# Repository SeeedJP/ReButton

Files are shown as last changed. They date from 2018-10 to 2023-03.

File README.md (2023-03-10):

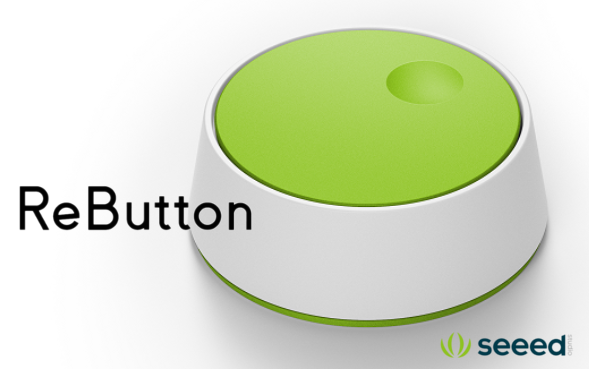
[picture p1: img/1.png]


ReButton is now available at [Seeed Bazaar](https://www.seeedstudio.com/ReButton-p-2930.html).

[日本語版ドキュメント](README-ja.md)

[HoL document in Simplified Chinese](IoTinAction_Hands-on%20Lab_ReButton%20OTA%20CN.pdf)

[!WARNING]
**Warning (Updated March 7, 2023)**

Due to the migration of the root certificate for Azure IoT Hub/Azure IoT Hub Device Provisioning Service planned from February 15, 2023 to February 15, 2024 [1], it is necessary to update ReButton's firmware to **v1.12 or later** [2].

Note that **OTA updates will fail** for firmware v1.0 to 1.11, so [firmware updates via SWD](#swd-serial-wire-debug) must be performed.

##### What is happening?
Between February 15, 2023 and February 15, 2024, the root certificate of the server certificate for Azure IoT Hub/Azure IoT Hub Device Provisioning Service will be gradually changed.

* Azure IoT Hub: February 15, 2023 to October 15, 2023
* Azure IoT Hub Device Provisioning Service: January 15, 2024 to February 15, 2024

##### What happens if I don't update the firmware?
After February 15, 2023, there is a possibility that ReButton will no longer be able to connect to Azure IoT Hub/IoT Central.

---
1. See "[Azure IoT TLS: Critical changes are almost here! (…and why you should care)](https://techcommunity.microsoft.com/t5/internet-of-things-blog/azure-iot-tls-critical-changes-are-almost-here-and-why-you/ba-p/2393169)" for more details.
2. Factory default firmware is "v1.0".
[!ENDWARNING]

# Overview

**Build IoT solutions with IoT Button!**

Seeed ReButton is a developer device for simple trigger actions, supporting multiple clicks and long press.
In addition, you can connect Seeed Grove sensors to add more data points.

1. When you push ReButton, it will power up and connect to Internet via pre-configured Wi-Fi.
2. ReButton will receive Device Twin changes from pre-configured Azure IoT Central or Azure IoT Hub.
3. ReButton will send Device to Cloud Message to pre-configured Azure IoT Central or Azure IoT Hub.
4. After D2C message is sent, ReButton will shutdown.

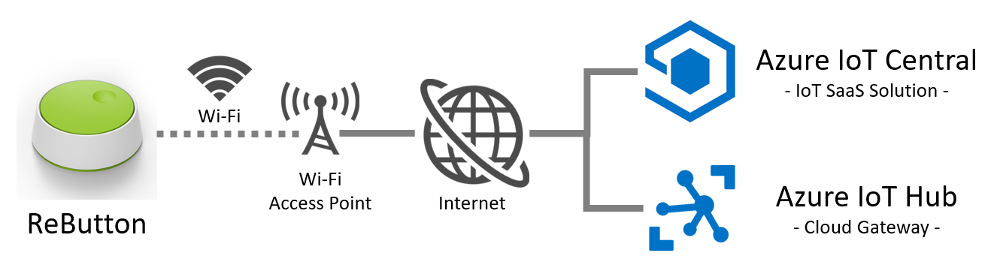
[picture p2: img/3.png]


# Key Features

## Multiple Trigger Support

* Single click
* Double click
* Triple click
* Long press (>3sec.)
* Super long press (>6sec.)

## Seeed Grove Sensor Support

Connect I2C or GPIO Grove sensors to the bottom of ReButton.
```
NOTE:
Software development/update is required.
```

## Cloud Support

Supports Azure IoT Central and Azure IoT Hub.

## OTA Support

You can update ReButton firmware over-the-air.

## Low Energy Design

ReButton runs with 2x AAA Alkaline battery.

# Quickstarts

## 1. Getting access to ReButton

Use AP Mode (Access Point Mode) to configure ReButton. **To avoid battery drain, ReButton will automatically shutdown in 10 minutes, at AP mode. So that we recommend you to setup IoT Hub or IoT Central, first.**

**AP Mode consume power. Please use fresh battery to start using ReButton.**

1. Hold button until RGB LED turns into White.
  RGB LED will start with Blue, Yellow, Cyan, then White. This will take about 10 seconds.

1. Release button and confirm ReButton is in AP mode.
  When ReButton successfully boots into AP Mode, RGB LED will blink in White.

1. Connect to AP
  Look for Wi-Fi Access Point `AZB-xxxxxxxxxxxx` and connect to it from your PC.
  (`xxxxxxxxxxxx` is MAC address of your ReButton Wi-Fi.)

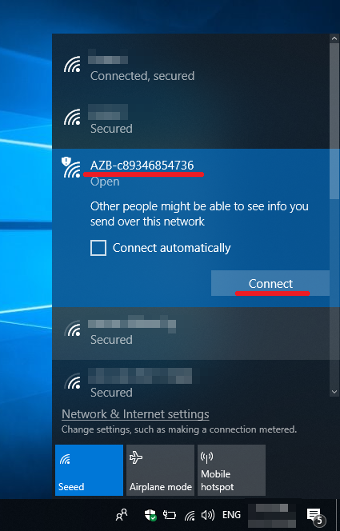
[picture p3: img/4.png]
  

4. Use a Web Browser to access ReButton - Home at `http://192.168.0.1`.

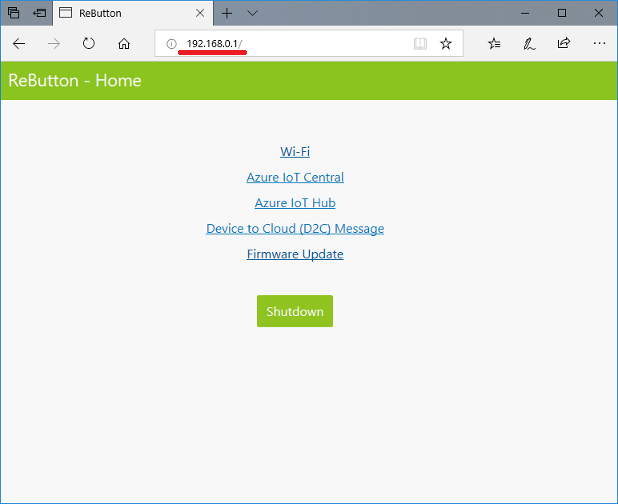
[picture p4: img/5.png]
  

## 2. Wi-Fi Configuration

Configure Wi-Fi settings to connect to Internet.

1. Click `Wi-Fi` at ReButton - Home.

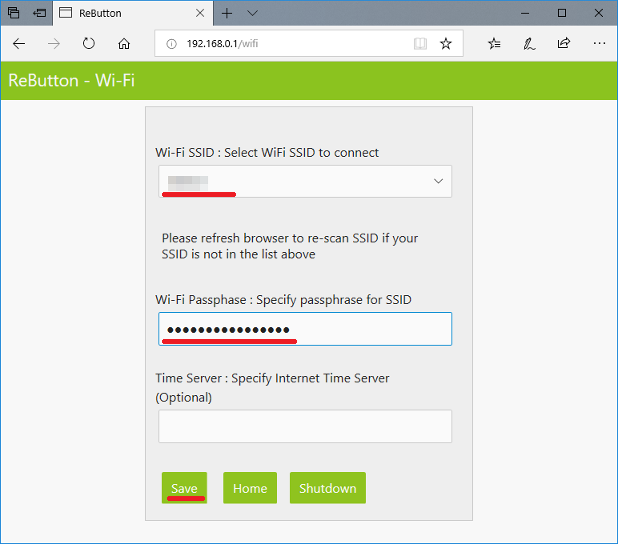
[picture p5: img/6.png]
  

2. Select your Wi-Fi Access Point from `Wi-Fi SSID` list.
  If you do not see your Access Point, refresh browser.
1. Enter `Wi-Fi Passphrase` for your Wi-Fi AP.
1. In case you would like to use specific Internet Time Server, enter FQDN to `Time Server`.
  _Default Internet Time Server is pool.ntp.org -> cn.pool.ntp.org -> europe.pool.ntp.org -> asia.pool.ntp.org -> oceania.pool.ntp.org ._

1. Click `Save`.

## 3. Cloud Configuration

### 3-1. Azure IoT Hub

**NOTE: Skip to next section if you would like to connct to Azure IoT Central.**

In order to send Device to Cloud (D2C) message to Azure IoT Hub, save Connection String in ReButton.

**To get the connection string, [This](IoT_Hub.md) page could be helpful.**

1. Browse to ReButton - Home page then click `Azure IoT Hub`.
1. Paste Connection String to `Azure IoT Hub connection string`.
1. Click `Save`.

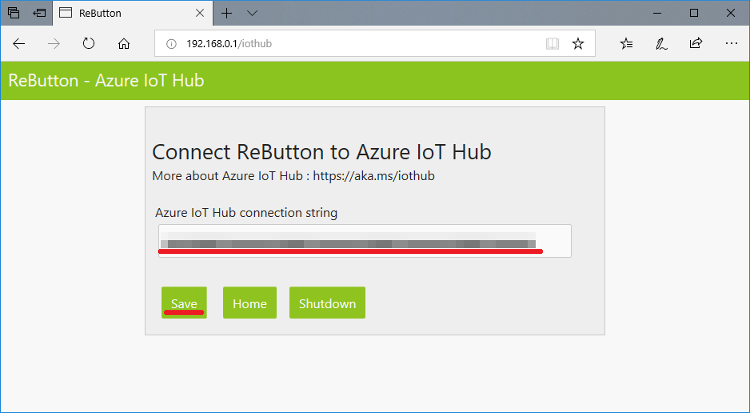
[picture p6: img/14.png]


### 3-2. Azure IoT Central

**NOTE: Skip this section if you already configured IoT Hub at section 3-1.**

In order to send Device to Cloud (D2C) message to Azure IoT Central, save device provisioning information in ReButton.

In order to connect ReButton to Azure IoT Central, the device template for ReButton needs to be defined in you Azure IoT Central Application. _Please refer [Azure IoT Central Document](https://docs.microsoft.com/en-us/azure/iot-central/howto-set-up-template) for more information._

1. Create a device template for ReButton in Azure IoT Central.

|Display name|Name|Capability type|Semantic type|Schema|Unit|
|:--|:--|:--|:--|:--|:--|
|Battery Voltage|batteryVoltage|Telemetry|Voltage|Double|Volt|
|Message|message|Telemetry|Event|String||
|Action Number|actionNum|Telemetry|Event|String||

- Battery Voltage

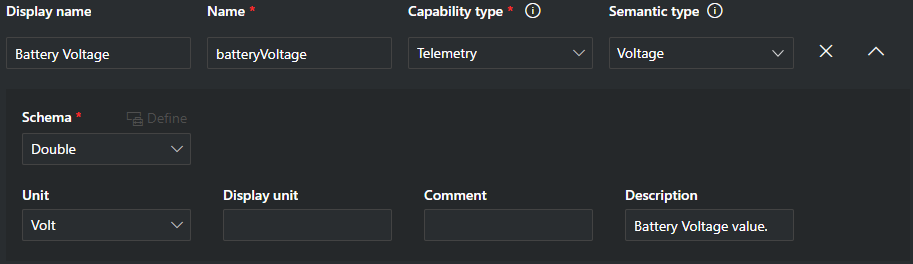
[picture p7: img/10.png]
  

- Message

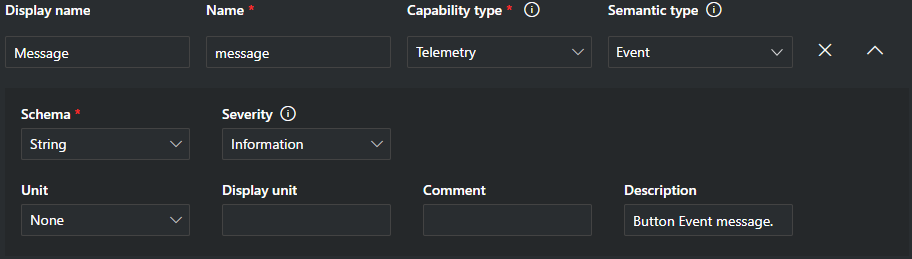
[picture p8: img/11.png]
  

- Action Number

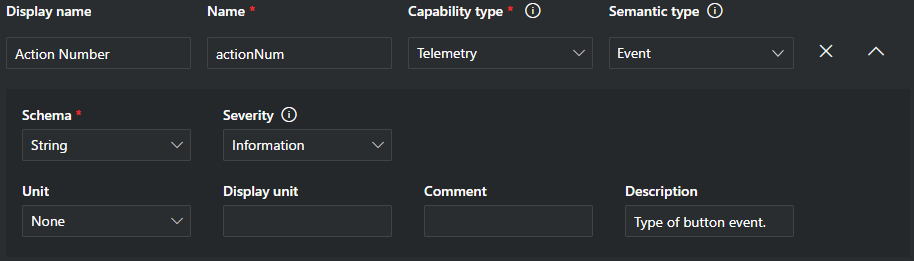
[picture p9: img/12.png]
  

2. Create a device in Azure IoT Central.

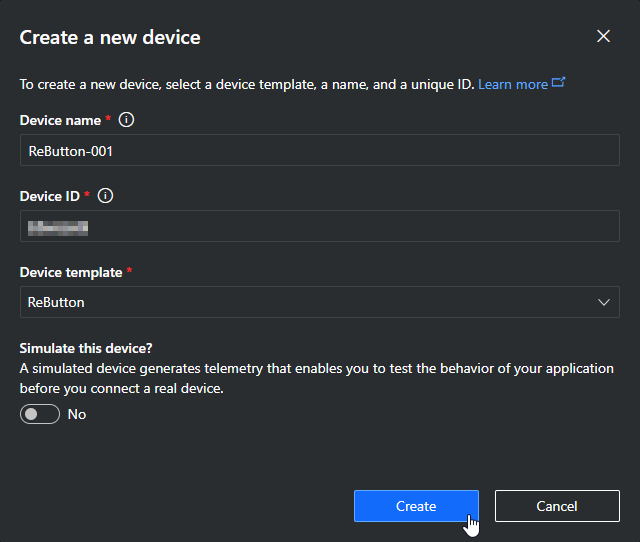
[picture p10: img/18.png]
  

3. Click `Connect` on Top Right corner of Azure IoT Central page.

  

4. Copy 3 values.
    1. `Scope ID`
    1. `Device ID`
    1. `Primary Key`

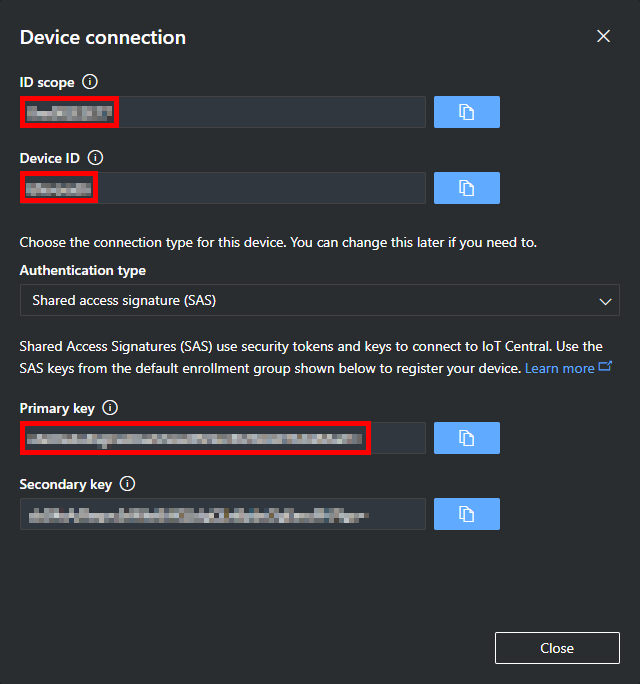
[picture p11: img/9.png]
  

5. Browse to ReButton - Home page then click `Azure IoT Central`.
1. Enter `Scope ID`, `Device ID`, `SAS Key` from Azure IoT Central.
1. Click `Save`.

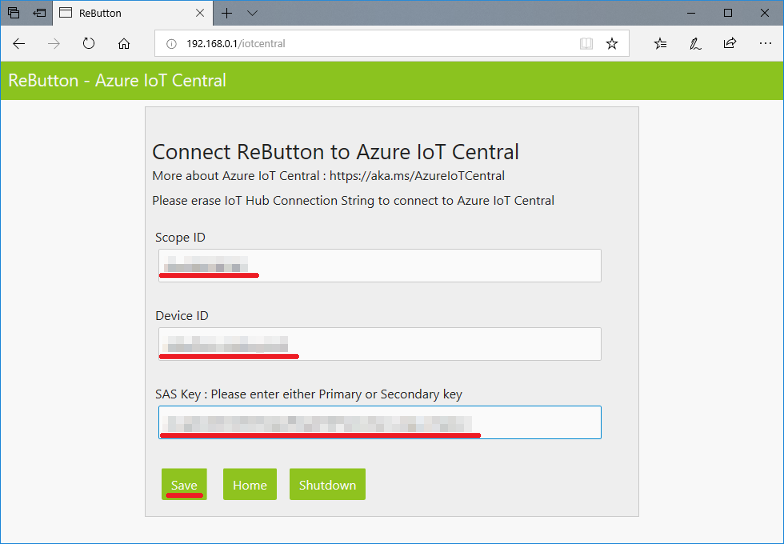
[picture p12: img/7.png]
  

## 4. Power off

Exit AP Mode and power off ReButton.

1. Click `Shutdown` button.

# Other informations
## Device To Cloud (D2C) Messsage

Button push will trigger D2C message to the cloud.
ReButton supports 5 types of button triggers and default D2C message strings are following.

|Clicks|RGB led|actionNum|message|
|:--|:--|:--|:--|
|Single click|Blue|1|"Single click"|
|Double click|Lime|2|"Double click"|
|Triple click|Magenta|3|"Triple click"|
|Long press (> 3sec.)|Yellow|10|"Long press"|
|Super long press (> 6sec.)|Cyan|11|"Super long press"|

Examples of D2C message:
```json
{
  "actionNum": "1",
  "message": "Single click",
  "batteryVoltage": 2.59
}

{
  "actionNum": "2",
  "message": "Double click",
  "batteryVoltage": 2.59
}

{
  "actionNum": "3",
  "message": "Triple click",
  "batteryVoltage": 2.59
}

{
  "actionNum": "10",
  "message": "Long press",
  "batteryVoltage": 2.59
}

{
  "actionNum": "11",
  "message": "Super long press",
  "batteryVoltage": 2.59
}
```

# Firmware Development
## Development environment
Please download and install [Arduino IDE](https://www.arduino.cc/en/Main/Software), not web editor.

On the preferenceof Arduino IDE, enter `https://www.seeed.co.jp/package_SeeedJP_index.json` to "Additional Boards Manager URLs".

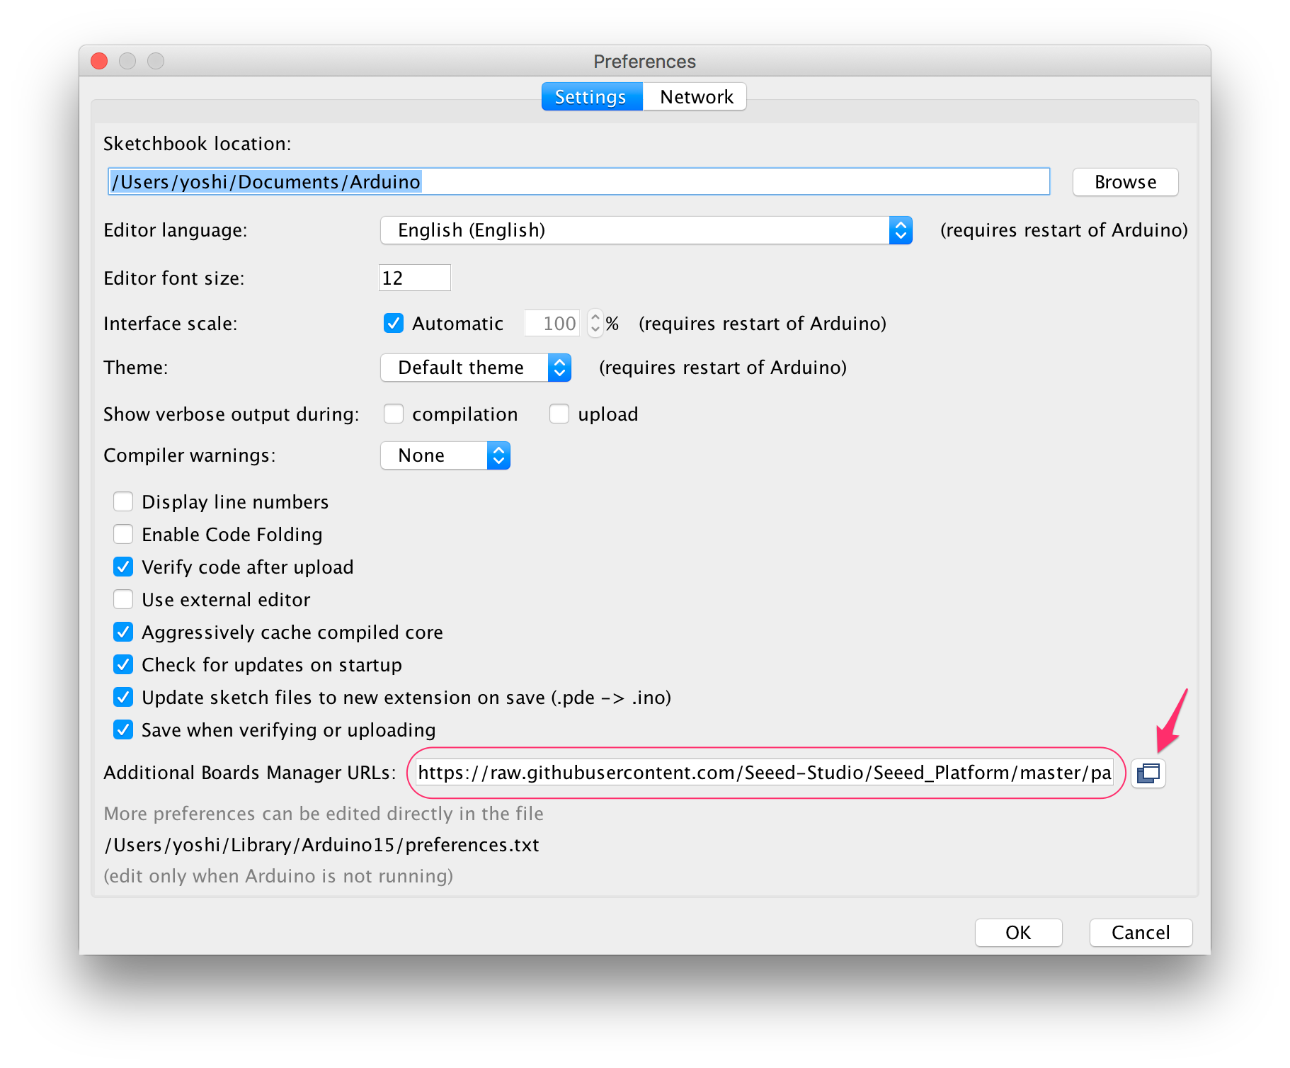
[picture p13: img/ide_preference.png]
ide_preference


Then goes to the Boards Manager from Tools > Board. And search ReButton board package by entering "rebutton". Then choose the candidate and click the "install" button.

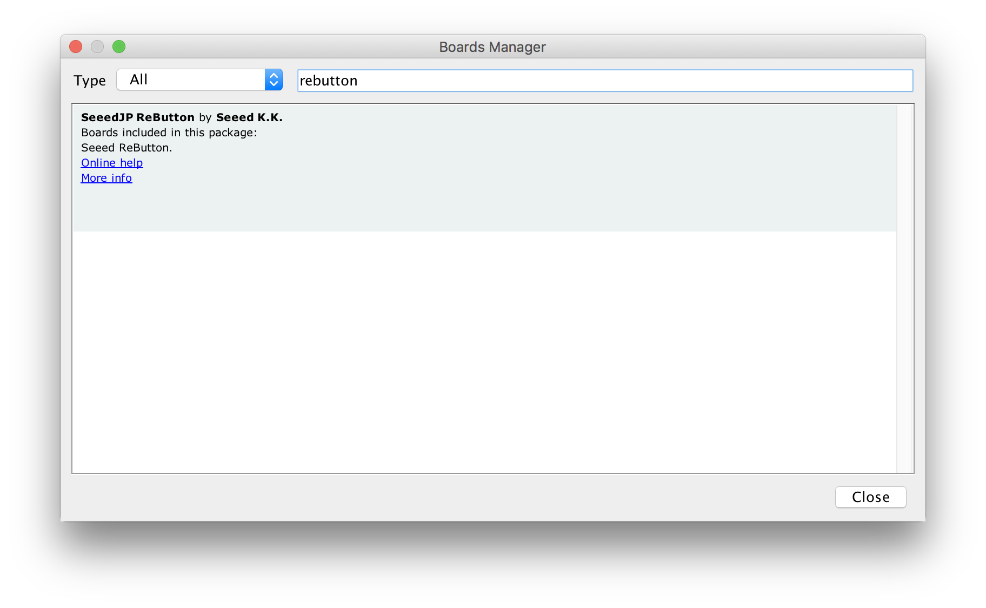
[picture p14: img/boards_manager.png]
boards_manager


After the install process ( it may take a few minutes ) you can choose "ReButton" through Tool -> Board on Arduino IDE.

## Firmware sample code
The source code is:
* [ReButton App](https://github.com/SeeedJP/ReButtonApp)

## Firmware OTA Update
ReButton supports Firmware OTA.
Browse to `Firmware Update` page to see the current vesrion of firmware and update to new firmware.

#### Current Firmware Version
Browse to ReButton - Home then click `Firmware Update` to see current firmware version of ReButton.

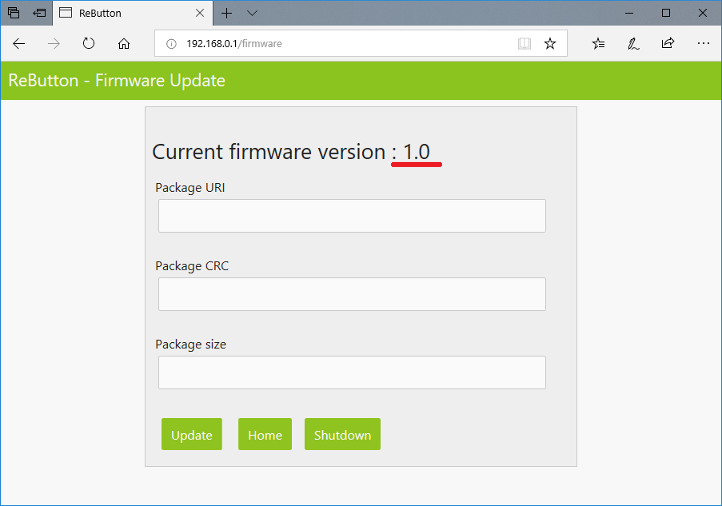
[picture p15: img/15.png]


#### How to update firmware through OTA
For OTA firmware update process, please refer [this](OTA.md) page.

## SWD (Serial Wire Debug)

ReButton has SWD pads for MCU development. **Please do this on your own risk,**  it is easy to make your ReButton brick.
Following picture show the SWD signals of the PAD. You can connect this PADs to debug adapters by using [TC2030-CTX 6-Pin Cable](http://www.tag-connect.com/TC2030-CTX) or solder directly to the PADs.

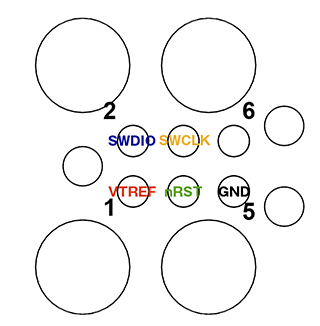
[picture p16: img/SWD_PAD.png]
SWD PADs


We are preparing for providing software development informations and affordable debug adapter. For your recovering purpose, you can download ReButton default firmware binary 'ReButton.1.0_with_bootloader.bin' from [here](https://github.com/SeeedJP/ReButton/tree/master/firmware). You need to flash this binary for target `STM32F412RG` and flash address `0x0800 0000` since this default firmware binary includes bootloader.

1. Connect the debug adapter to ReButton's SWD pads.
2. Install batteries.
3. **While holding (physical) button of ReButton**, execute download.

example:
```
openocd -f /usr/local/share/openocd/scripts/interface/cmsis-dap.cfg -c 'transport select swd' -f /usr/local/share/openocd/scripts/target/stm32f4x.cfg -c "program ReButton.1.0_with_bootloader.bin verify reset exit 0x08000000"
```

When you flash a binary without bootloader (such as `ReButtonApp.1.x.bin`), you should flash address `0x0800 C000`.

# Specification

## Hardware

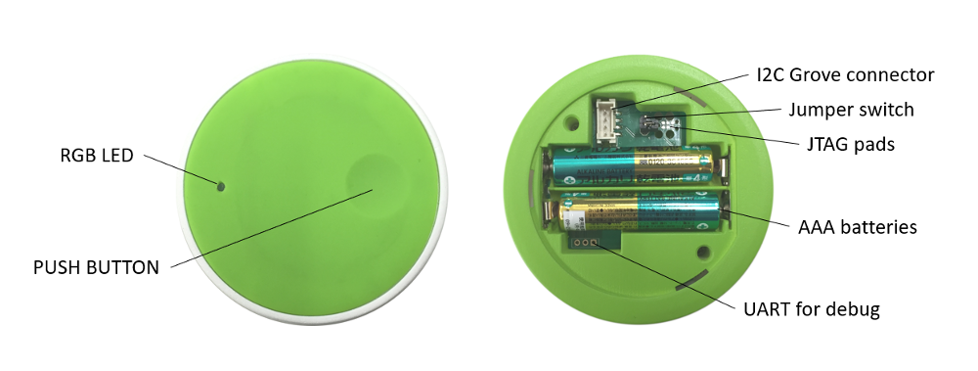
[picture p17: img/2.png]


|Description|Value|
|:--|:--|
|MCU module|MXCHIP EMW3166|
|Input|1x Push button|
|Output|1x RGB led|
|Extension|1x I2C Grove connector (3.3V I/O)|
|Extras|1x Jumper switch|
||1x SWD pads|
||1x UART for debugging|
|Power supply|2x AAA Alkaline batteries (LR03)|
|Internal supply voltage|3.3V|
|Dimension|70mm\*70mm\*25mm|

## Design files
* [Schematics](https://github.com/SeeedJP/ReButton/tree/master/electronics)
* [Housing](https://github.com/SeeedJP/ReButton/tree/master/mechanicals)


These files are licensed under [CC-BY-SA](https://creativecommons.org/licenses/by-sa/4.0/deed.en).

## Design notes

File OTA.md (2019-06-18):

## Step 1 : Uploading firmware binary to Azure Storage

You can upload ReButton firmware binary to Azure Storage wiith [Azure CLI](https://docs.microsoft.com/en-us/cli/azure/) tool.

### 1.1 : Install Azure CLI

Please refer to Azure CLI install instruction [here](https://docs.microsoft.com/en-us/cli/azure/install-azure-cli).

And [Using the Azure CLI with Azure Storage](https://docs.microsoft.com/en-us/azure/storage/common/storage-azure-cli) page is helpful to process things on this instruction.

### 1.2 : Create a new storage account

To use Azure Storage, you need a storage account. You can create a new Azure Storage account after you've configured your computer to connect to your subscription.

```bash
az storage account create \
    --location <location> \
    --name <account_name> \
    --resource-group <resource_group> \
    --sku <account_sku>
```
e.g.
```bash
az storage account create --location japaneast \
--name seeedkk --resource-group ReButton --sku Standard_GRS
```
You can use same resource group to IoT Hub.

### 1.3: Set default Azure storage account

First, display your storage account keys by using following account.
```bash
az storage account keys list \
    --account-name <account_name> \
    --resource-group <resource_group> \
    --output table
```
e.g.
```bash
az storage account keys list --account-name seeedkk \
--resource-group ReButton
```

Now that you have the key, you can define it and the account name as environment variables:

```bash
export AZURE_STORAGE_ACCOUNT=<account_name>
export AZURE_STORAGE_KEY=<key>
```

### 1.4 Create a container

Every blob in Azure storage must be in a container. You can create a container by using following command.
```bash
az storage container create --name <container_name> \
--public-access container
```

### 1.5 Upload a blob to a container

And you can upload firmware binary to Azure storage with following command.
```bash
az storage blob upload \
    --file <local_file_path> \
    --container-name <container_name> \
    --name <blob_name>
```
e.g.
```bash
az storage blob upload -f ReButtonApp.1.0.bin \
--container-name rebuttonfirm --name ReButtonApp.1.0.bin
```

### 1.6: Grab the URL

You can find the URL of uploaded blob on [Azure Portal](https://portal.azure.com).

On the portal, please find `Storage accounts` in `All services` and then choose storage accounts you used to upload, and choose `Blobs`.

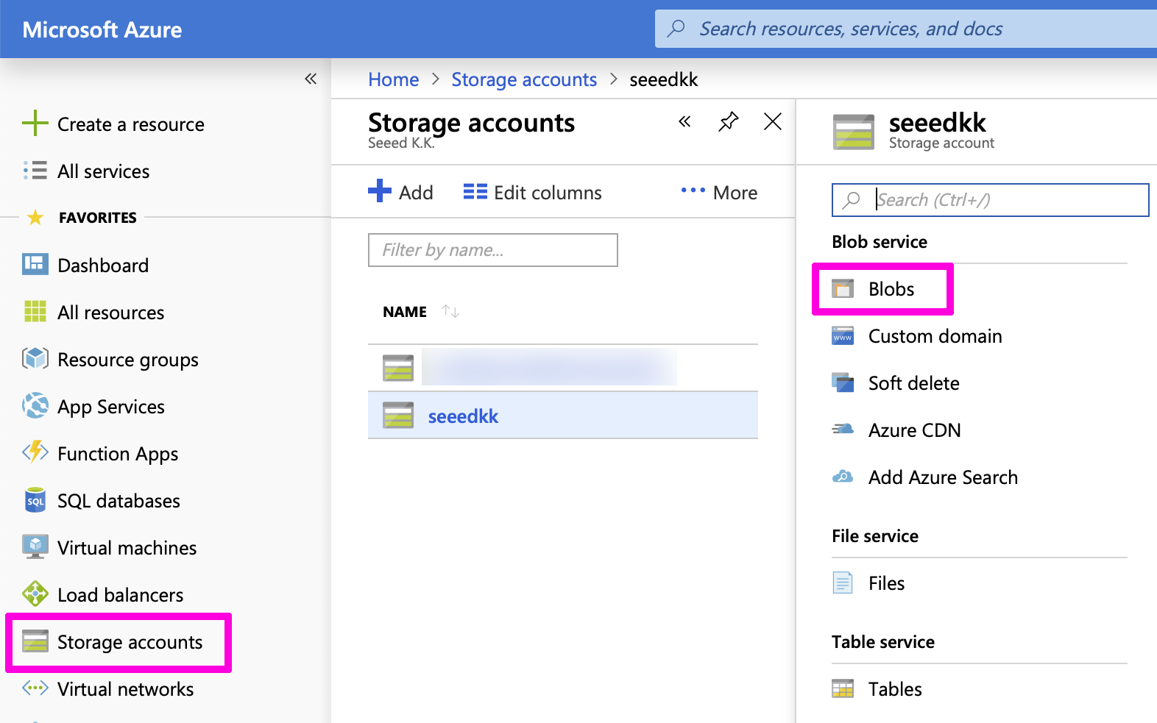
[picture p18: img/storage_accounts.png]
storage accounts


In the container you have just used, you can find uploaded file(blob). By clicking the filename, you can refer the URL.

## Step 2: Calculate CRC

CRC can calclulate with [generatecrc](https://github.com/SeeedJP/ReButton/tree/master/tools/generatecrc) command we are providing in this repository.

example:
```bash
$ cd generatecrc
$ ./generatecrc ../ReButtonApp.1.0.bin
========== ReButton Firmware Information ==========

Package path: ../ReButtonApp.1.0.bin
Package CRC: 0xbc3b
Package size: 641924

===================================================
```

## Step 3: OTA process

**OTA consume power. Please use fresh battery, not to interrupt OTA process.**

1. Enter ReButton to AP mode by press hold the button until RGB LED turns into White. 
   (reminder: connect to the AP `AZB-xxxxxxxxxxxx` and the URL of the page is `http://192.168.0.1`)
1. Browse to ReButton - Home page then click `Firmware Update`.
1. Enter following information.
  - `Package URI` - got on Step 1.6
  - `Package CRC` - got on Step 2.
  - `Package Size` - got on Step 2.
1. **While holding (physical) button of ReButton**, click `Update`.
1. Hold button until RGB LED starts blinking. ReButton is downloading the firmware image, checking CRC, and flashing new image. **This will take about 30 seconds.**
1. Release button when RGB LED turns into White. So that you are entering AP mode with new firmware.
1. Please set-up ReButton Wi-Fi connection and Azure connection settings on this AP mode.

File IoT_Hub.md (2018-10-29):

# Getting started with Azure IoT Hub
---
Legal Disclaimer  
This page was provided just to provide a convenience for users. Seeed is not responsible for any errors or omissions, or for the results obtained from the use of this information. All information in this page is provided "as is", with no guarantee of completeness, accuracy, timeliness or of the results obtained from the use of this information.

---

For more information about "Azure IoT Hub", please refer to [Azure IoT Hub](https://docs.microsoft.com/en-us/azure/iot-hub/about-iot-hub).

For pricing information about IoT Hub tiers refer to [IoT Hub pricing](https://azure.microsoft.com/en-us/pricing/details/iot-hub/).

## Step 1 : Login to Azure Portal

If you don't have an active Azure subscription, create a [free account](https://azure.microsoft.com/free) before you begin.

## Step 2 : Create Azure IoT Hub

### 2.1 : Navigate to [Azure Portal](http://portal.azure.com) with browser

### 2.2 : Click `Create a resource` on top left corner  

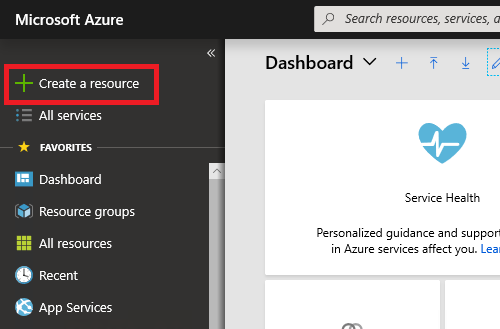
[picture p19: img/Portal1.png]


### 2.3 : Select `Internet of Things`, then `IoT Hub`
  
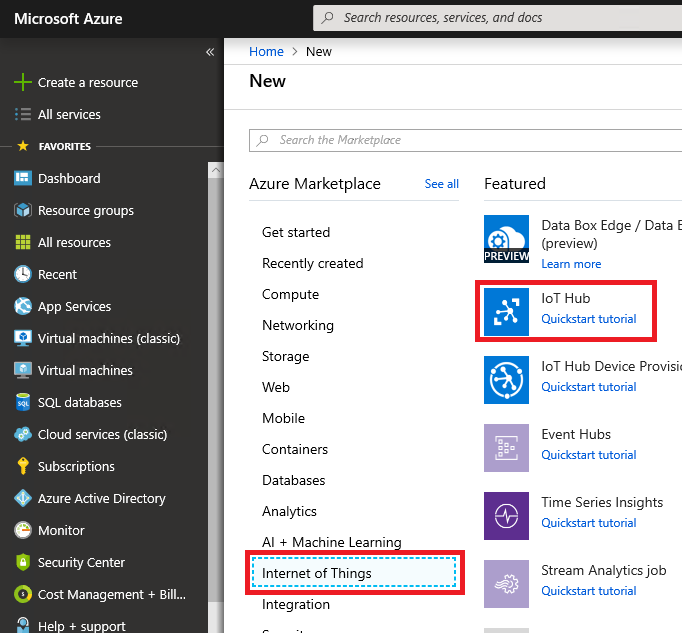
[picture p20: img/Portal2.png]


### 2.4 : Fill out following fields

|Field | Description  |
|---|---|
|Subscription | Your subscription.  Select from the list. |
|Resource Group  | A resource group to manage all the resources.  Select existing one from the list or create new group. |
|Region | Location of Azure Data Center.  Select the one close to you. |
|IoT Hub Name | Provide a globally unique name for your IoT Hub. |

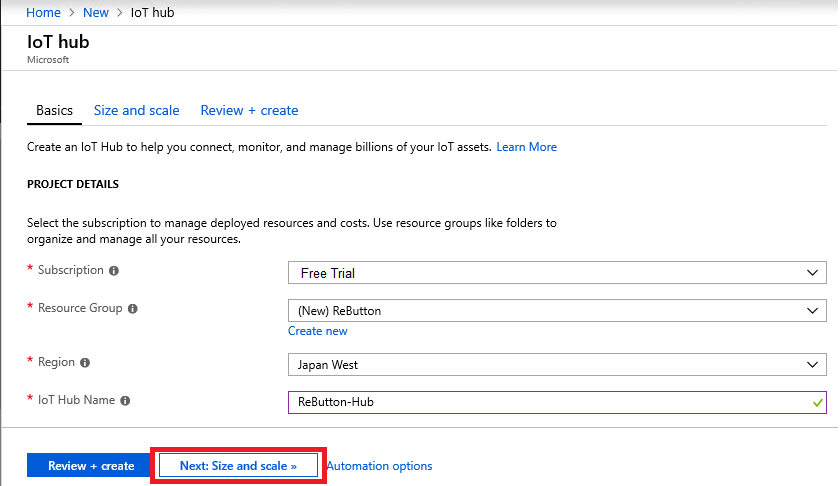
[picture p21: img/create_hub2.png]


### 2.5 : Size and Scale

Click `Size and scale`, then select `F1 : Free tier`.  

_NOTE: Only one F1 Free tier is available per subscription. If you already have F1 IoT Hub, you may need non-free tier IoT Hub. More about [IoT Hub tier](https://docs.microsoft.com/en-us/azure/iot-hub/iot-hub-scaling)._

### 2.6 : Click `Review + create` button

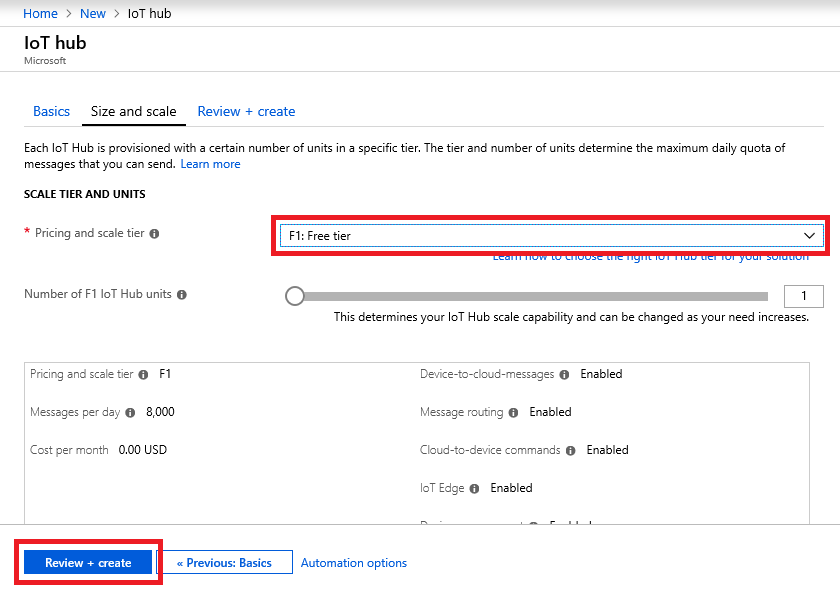
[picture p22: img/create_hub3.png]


### 2.7 : Create Azure IoT Hub

Review your settings then, click `Create` button.

Wait until the deployment completes.

## Step 3 : Create IoT Device

### 3.1 : Navigate to Azure IoT Hub instance

After your new Azure IoT Hub is deployed, click your Azure IoT Hub resource to navigate to Azure IoT Hub instance you just created.

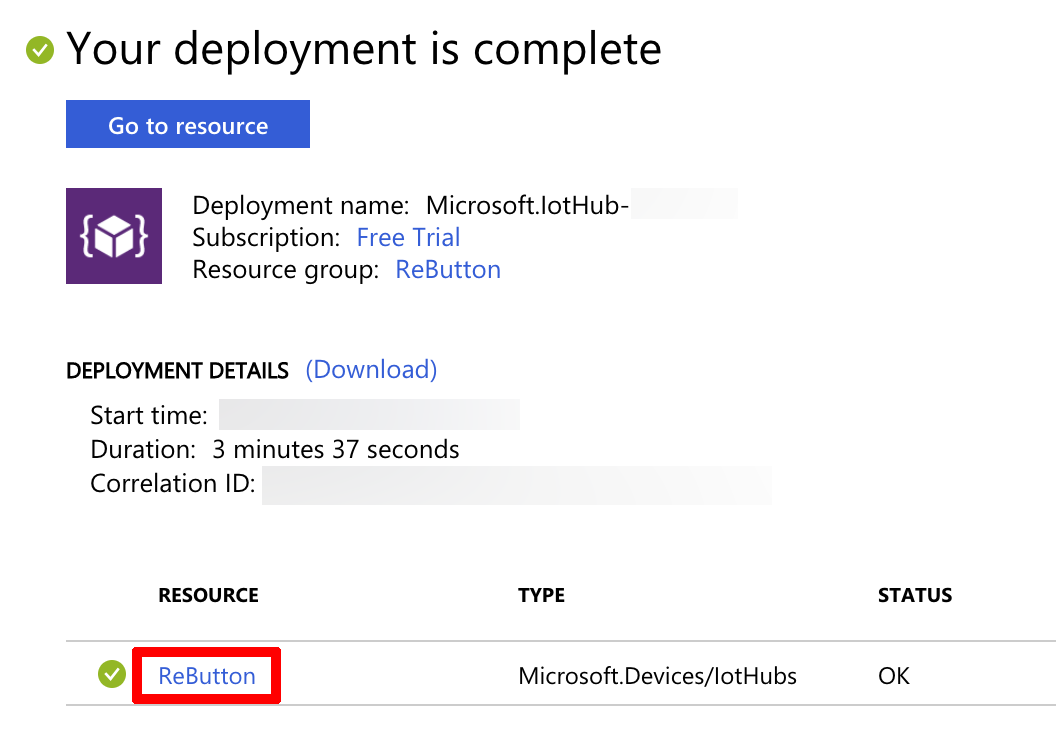
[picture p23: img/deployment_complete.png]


### 3.2 : Create IoT Device

Click  `IoT Devices`

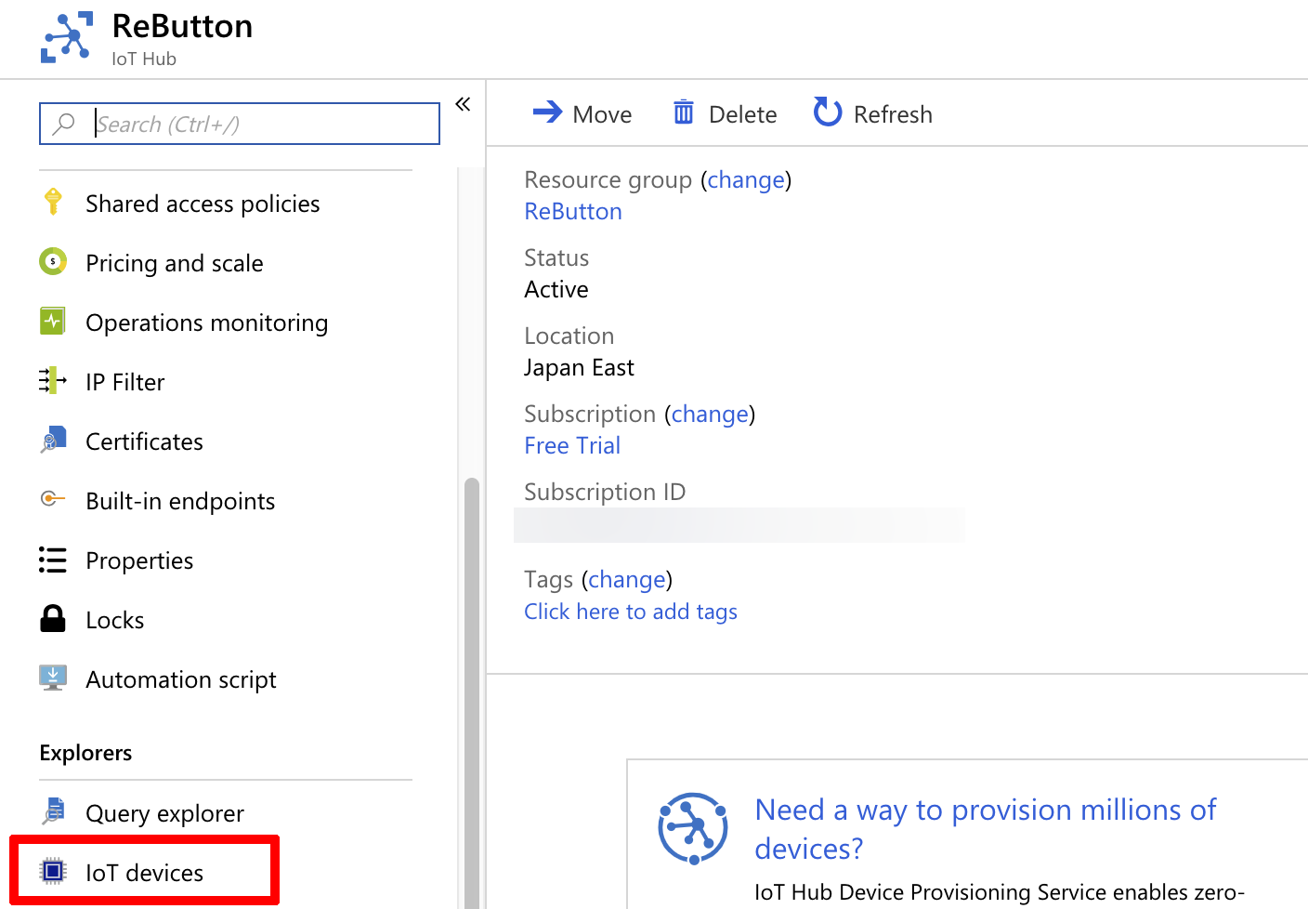
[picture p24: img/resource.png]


### 3.3 : Click `Add` button

To add a new IoT Device to your Azure IoT Hub

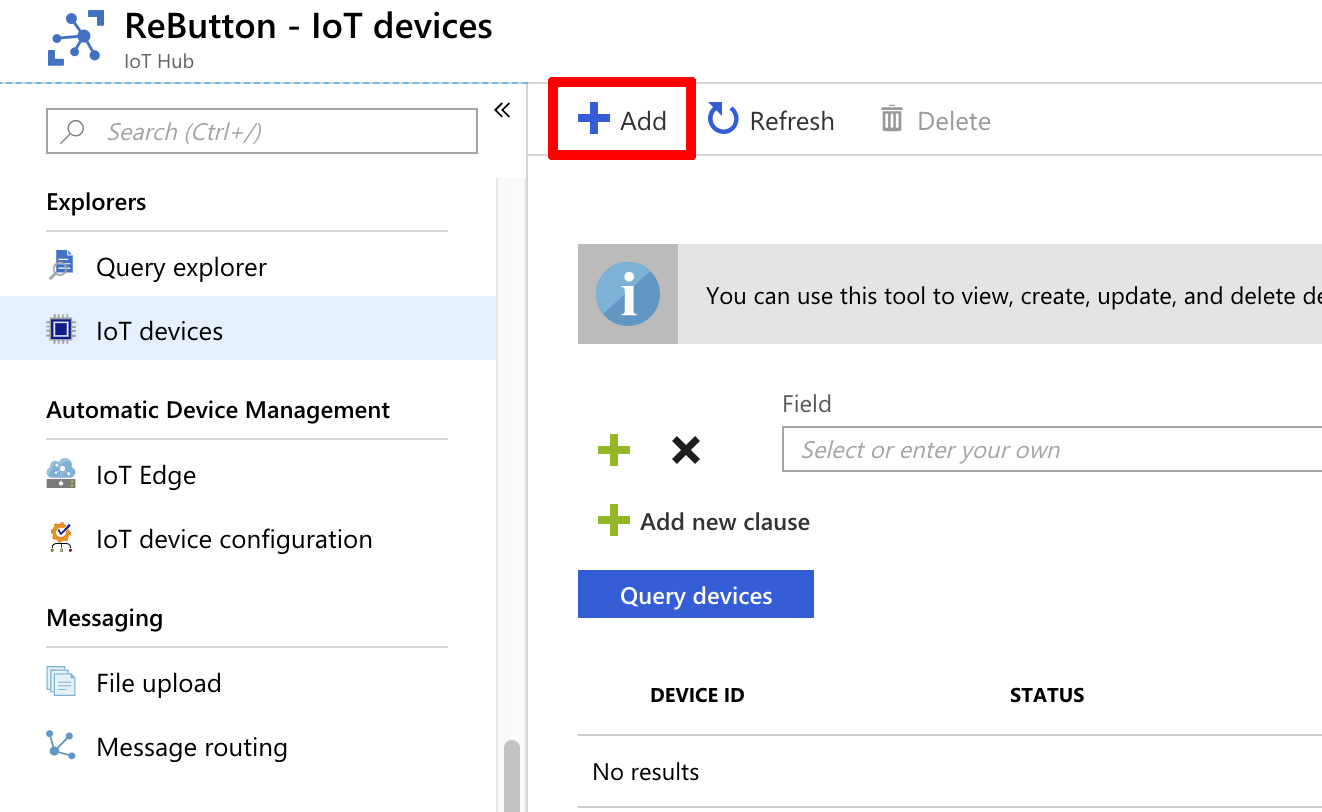
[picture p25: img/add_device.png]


### 3.4 : Provide a name to new IoT Device

Set Device Id (Name) for your ReButton, then click `Save` button

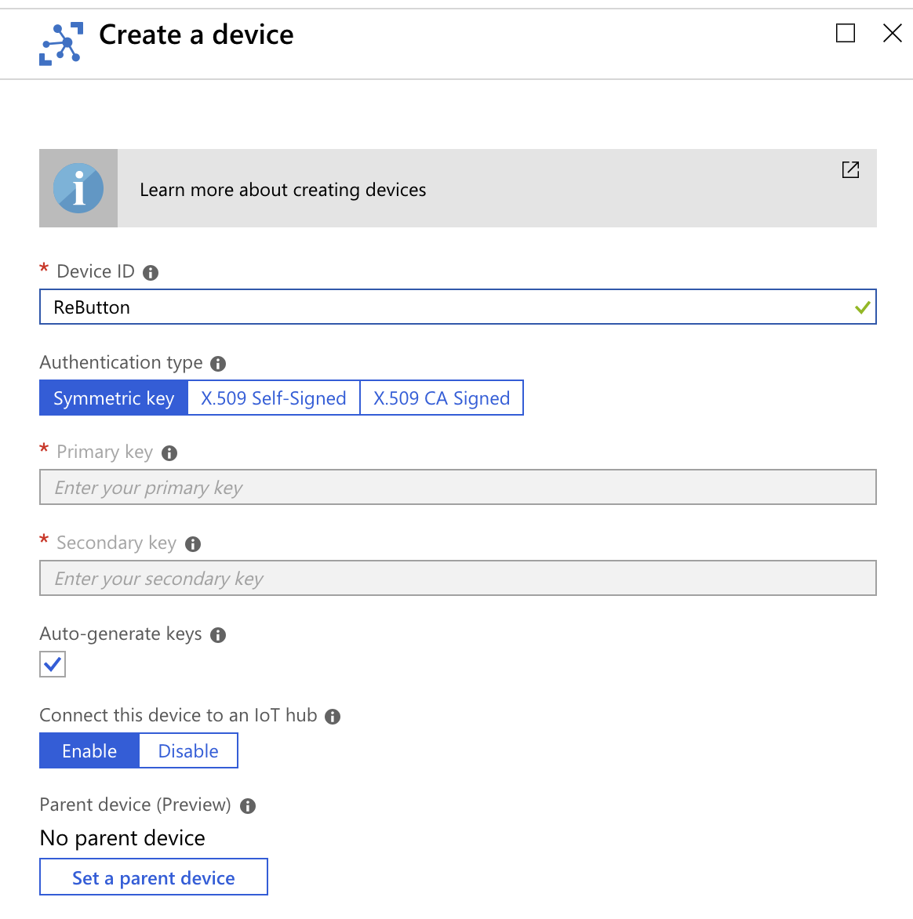
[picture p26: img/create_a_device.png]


### 3.5 : Verify a new IoT Device for ReButton is created

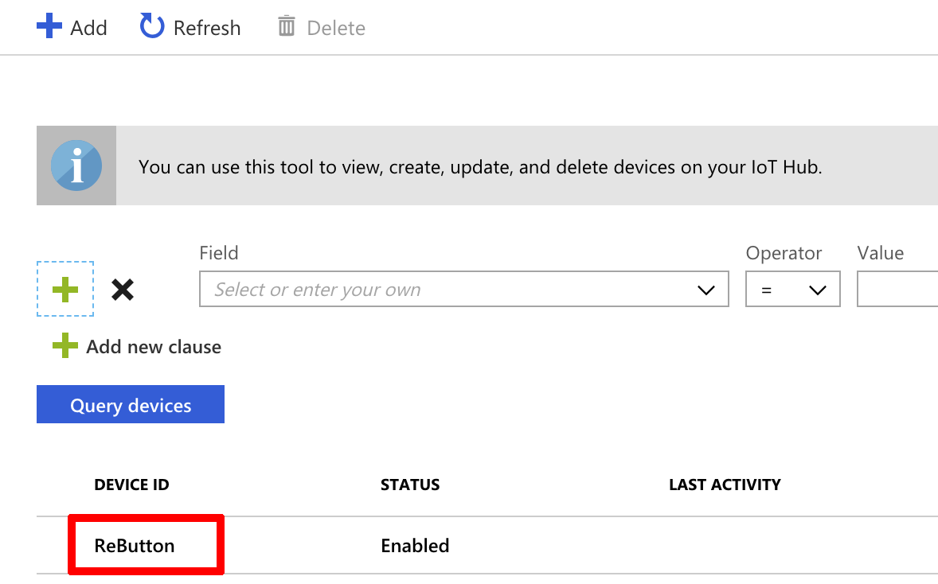
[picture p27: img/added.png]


## Step 4 : Connect ReButton to Azure IoT Hub

In order for ReButton to securely connect to Azure IoT Hub, Connection String needs to be saved  to ReButton.

### 4.1 : Open Device Detail page

Click on the newly created IoT Device (e.g. ReButton) to open `Device details` page.

### 4.2 : Copy `Connection String`

Copy either Primary or Secondary Connection String by clicking button on the right

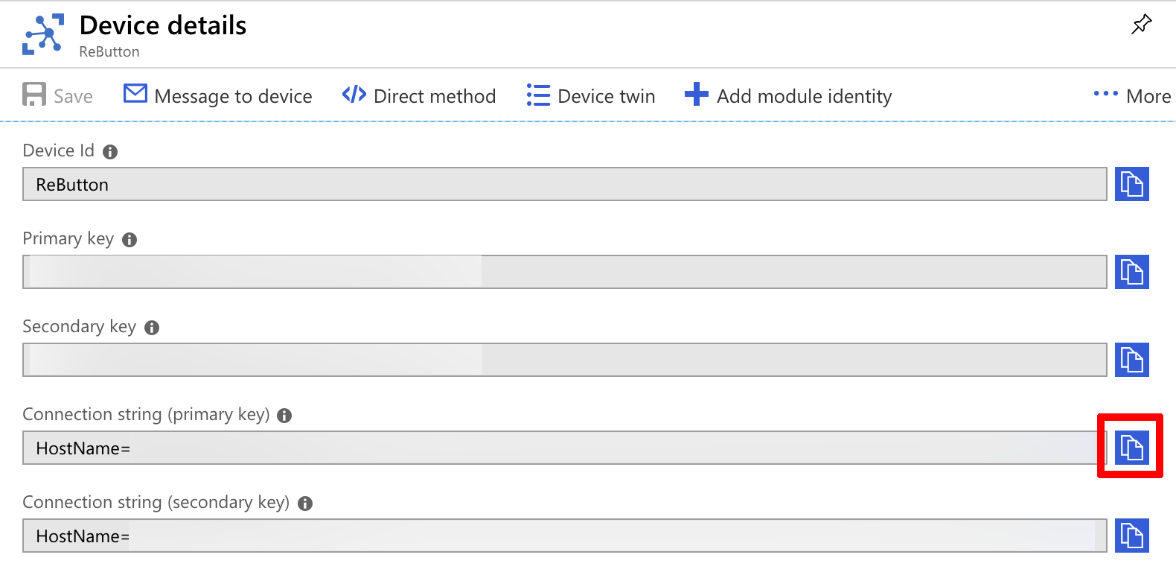
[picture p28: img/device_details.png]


### 4.3 : Save Connection String to ReButton Device

Please refer to [3-1. Azure IoT Hub](README.md#3-1-azure-iot-hub)

## Step 5 : Verify Connection

With [Azure CLI](https://docs.microsoft.com/en-us/cli/azure/) tool, verify ReButton sends messages to Azure IoT Hub.

### 5.1 : Install Azure CLI

Please refer to Azure CLI install instruction [here](https://docs.microsoft.com/en-us/cli/azure/install-azure-cli)

### 5.2 : Install IoT Extension

Install [Azure IoT extension for Azure CLI](https://github.com/Azure/azure-iot-cli-extension) with following command

```
$ az extension add --name azure-cli-iot-ext
```  

### 5.3 : Login to Azure

After getting Azure CLI installed, login to Azure

```
$ az login
```  

Web browser will launch to complete login process

### 5.4 : List Azure IoT Hub

Let's list your IoT Hub(s)  

```
$ az iot hub list
``` 

### 5.5 : Monitor Device to Cloud (D2C) message

To monitor messages from `ReButton` to IoT Hub, please run command.  

_NOTE: Replace [IoTHub Name] with your Azure IoT Hub instance from list command above._

```
$ az iot hub monitor-events -n [IoTHub Name] --properties anno sys --timeout 0
```

For more information about Azure CLI command, please see help,  

```
$ az iot hub monitor-events --help
```

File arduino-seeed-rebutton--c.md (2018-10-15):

---
platform: arduino
device: Seeed ReButton
language: c
---

Run a simple C sample on Seeed ReButton device running Arduino
===
---

# Table of Contents

-   [Introduction](#Introduction)
-   [Step 1: Prerequisites](#Prerequisites)
-   [Step 2: Prepare your Device](#PrepareDevice)
-   [Step 3: Configure and Run the Sample](#Run)
-   [Next Steps](#NextSteps)

# Introduction

This document describes how to connect Seeed ReButton device running C with Azure IoT Hub. This multi-step process includes:
-   Configuring Azure IoT Hub
-   Registering your IoT device
-   Configure the device and run the sample

# Step 1: Prerequisites

You should have the following items ready before beginning the process:

-   [Setup your IoT hub][lnk-setup-iot-hub]
-   [Provision your device and get its credentials][lnk-manage-iot-hub]
-   Seeed ReButton device.

# Step 2: Prepare your Device

# Step 3: Run the sample

## 3.1 Access to ReButton

Use AP Mode (Access Point Mode) to configure ReButton.

1. Hold button until RGB LED turns into White.  
  RGB LED will start with Blue, Yellow, Cyan, then White.  
  This will take about 10 seconds.

1. Release button and confirm ReButton is in AP mode.  
  When ReButton successfully boots into AP Mode, RGB LED will blink in White.

1. Connect to AP  
  Look for Wi-Fi Access Point `AZB-xxxxxxxxxxxx` and connect to it from your PC.  
  `xxxxxxxxxxxx` is MAC address of your ReButton Wi-Fi.  
  

1. Use a Web Browser to access ReButton - Home at `http://192.168.0.1`.  
  

## 3.2 Wi-Fi Configuration

Configure Wi-Fi settings to connect to Internet.

1. Click `Wi-Fi` at ReButton - Home.
1. Select your Wi-Fi Access Point from `Wi-Fi SSID` list.  
  If you do not see your Access Point, refresh browser.
1. Enter `Wi-Fi Passphrase` for your Wi-Fi AP.
1. In case you would like to use specific Internet Time Server, enter FQDN to `Time Server`.  
  Default Internet Time Server is pool.ntp.org -> cn.pool.ntp.org -> europe.pool.ntp.org -> asia.pool.ntp.org -> oceania.pool.ntp.org .

1. Click `Save`.



### 3.3 Azure IoT Hub

In order to send Device to Cloud (D2C) message to Azure IoT Hub, save Connection String in ReButton.

1. Browse to ReButton - Home page then click `Azure IoT Hub`.
1. Paste Connection String to `Azure IoT Hub connection string`.
1. Click `Save`.



## 3.4 Power off

Exit AP Mode and power off ReButton.

1. Click `Shutdown` button.

## 3.5 Device To Cloud (D2C) Messsage

Button push will trigger D2C message to the cloud.  
ReButton supports 5 types of button triggers and default D2C message strings are following.

|Clicks|RGB led|actionNum|message|
|:--|:--|:--|:--|
|Single click|Blue|1|"Single click"|
|Double click|Lime|2|"Double click"|
|Triple click|Magenta|3|"Triple click"|
|Long press (> 3sec.)|Yellow|10|"Long press"|
|Super long press (> 6sec.)|Cyan|11|"Super long press"|

Examples of D2C message:
```json
{
  "actionNum": "1",
  "message": "Single click",
  "batteryVoltage": 2.59
}

{
  "actionNum": "2",
  "message": "Double click",
  "batteryVoltage": 2.59
}

{
  "actionNum": "3",
  "message": "Triple click",
  "batteryVoltage": 2.59
}

{
  "actionNum": "10",
  "message": "Long press",
  "batteryVoltage": 2.59
}

{
  "actionNum": "11",
  "message": "Super long press",
  "batteryVoltage": 2.59
}
```

# Next Steps

You have now learned how to run a sample application that collects sensor data and sends it to your IoT hub. To explore how to store, analyze and visualize the data from this application in Azure using a variety of different services, please click on the following lessons:

-   [Manage cloud device messaging with iothub-explorer]
-   [Save IoT Hub messages to Azure data storage]
-   [Use Power BI to visualize real-time sensor data from Azure IoT Hub]
-   [Use Azure Web Apps to visualize real-time sensor data from Azure IoT Hub]
-   [Weather forecast using the sensor data from your IoT hub in Azure Machine Learning]
-   [Remote monitoring and notifications with Logic Apps]   

[Manage cloud device messaging with iothub-explorer]: https://docs.microsoft.com/en-us/azure/iot-hub/iot-hub-explorer-cloud-device-messaging
[Save IoT Hub messages to Azure data storage]: https://docs.microsoft.com/en-us/azure/iot-hub/iot-hub-store-data-in-azure-table-storage
[Use Power BI to visualize real-time sensor data from Azure IoT Hub]: https://docs.microsoft.com/en-us/azure/iot-hub/iot-hub-live-data-visualization-in-power-bi
[Use Azure Web Apps to visualize real-time sensor data from Azure IoT Hub]: https://docs.microsoft.com/en-us/azure/iot-hub/iot-hub-live-data-visualization-in-web-apps
[Weather forecast using the sensor data from your IoT hub in Azure Machine Learning]: https://docs.microsoft.com/en-us/azure/iot-hub/iot-hub-weather-forecast-machine-learning
[Remote monitoring and notifications with Logic Apps]: https://docs.microsoft.com/en-us/azure/iot-hub/iot-hub-monitoring-notifications-with-azure-logic-apps
[lnk-setup-iot-hub]: ../setup_iothub.md
[lnk-manage-iot-hub]: ../manage_iot_hub.md

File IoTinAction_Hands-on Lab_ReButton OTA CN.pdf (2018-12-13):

WinHEC

# ReButton WiFi Config & OTA updates

Abstract: Add abstract here (Note that a long title may push the abstract down the page. Just delete some line breaks above the abstract if you need to reposition it).

# Hands-on Lab

Copyright (c) 2018 Microsoft. All rights reserved.

This document is provided "as-is." Information and views expressed in this document, including URL and other Internet Web site references, may change without notice.

## What you learn

1. 使用 Visual Studio Code 进行编译
2. 如何使用 OTA 完成软体的更新
3. 完成 ReButton 的 WiFi 设置

## What you need

1. A ReButton
2. A computer running Windows 10 or macOS 10.10+
3. Visual Studio Code
4. Arduino IDE
5. An active Azure subscription. Activate a free 30-day trial Microsoft Azure account.

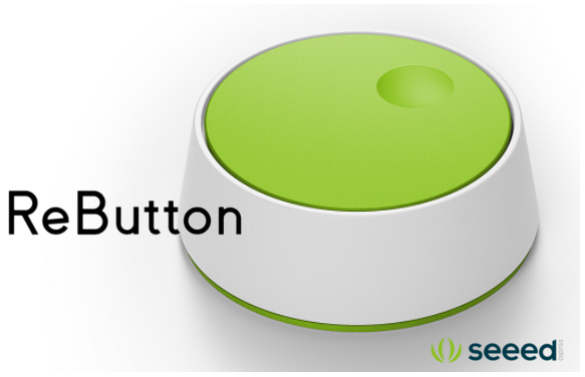
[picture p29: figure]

### 如何使用 OTA 完成软体的更新

1. 长按按键，一直按到按键是白灯状态，松开按键，这时，你会看到 LED 是白灯在闪烁。
2. 打开 PC 的 WiFi 选项，连接 AP AZB-xxxxxxxxxxxx, xxxxxxxxxxxx 是 MAC 地址。
3. 打开浏览器，输入 http://192.168.0.1
4. 点击 Firmware Update

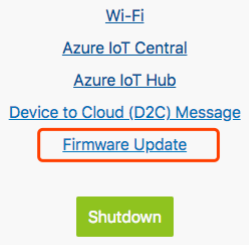
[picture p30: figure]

### 5. url 请输入：https://rebutton.blob.core.windows.net/test/ReButton20.bin CRC 请输入：0x38cd

Package size 请输入：644960
6. 按住按键，然后点击网页端的 Update

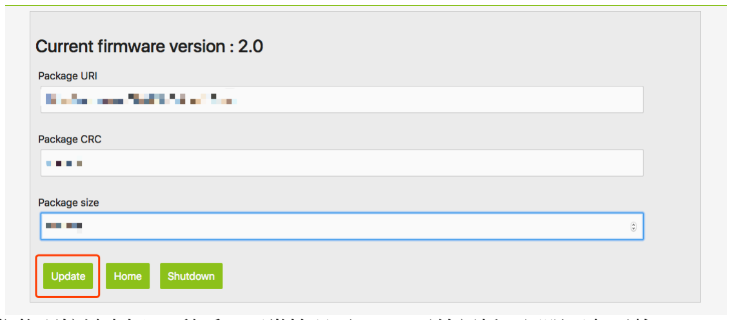
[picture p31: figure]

7. 按住物理按键大概 10 秒后，正常情况下，LED 开始闪烁，证明正在下载
8. 一直到 LED 的颜色变成白色，便可以松开物理按键
9. 重新连接 AP 进入 http://192.168.0.1
10. 点击 Firmware Update， 进去里面可以看见 标题为 Current firmware version 是 2.0，证明已
经烧写成功。

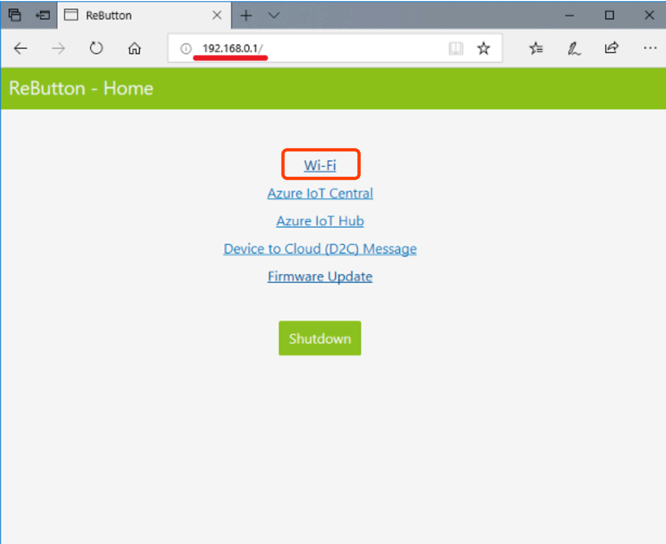
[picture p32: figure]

## 使用 Visual Studio Code 进行编译

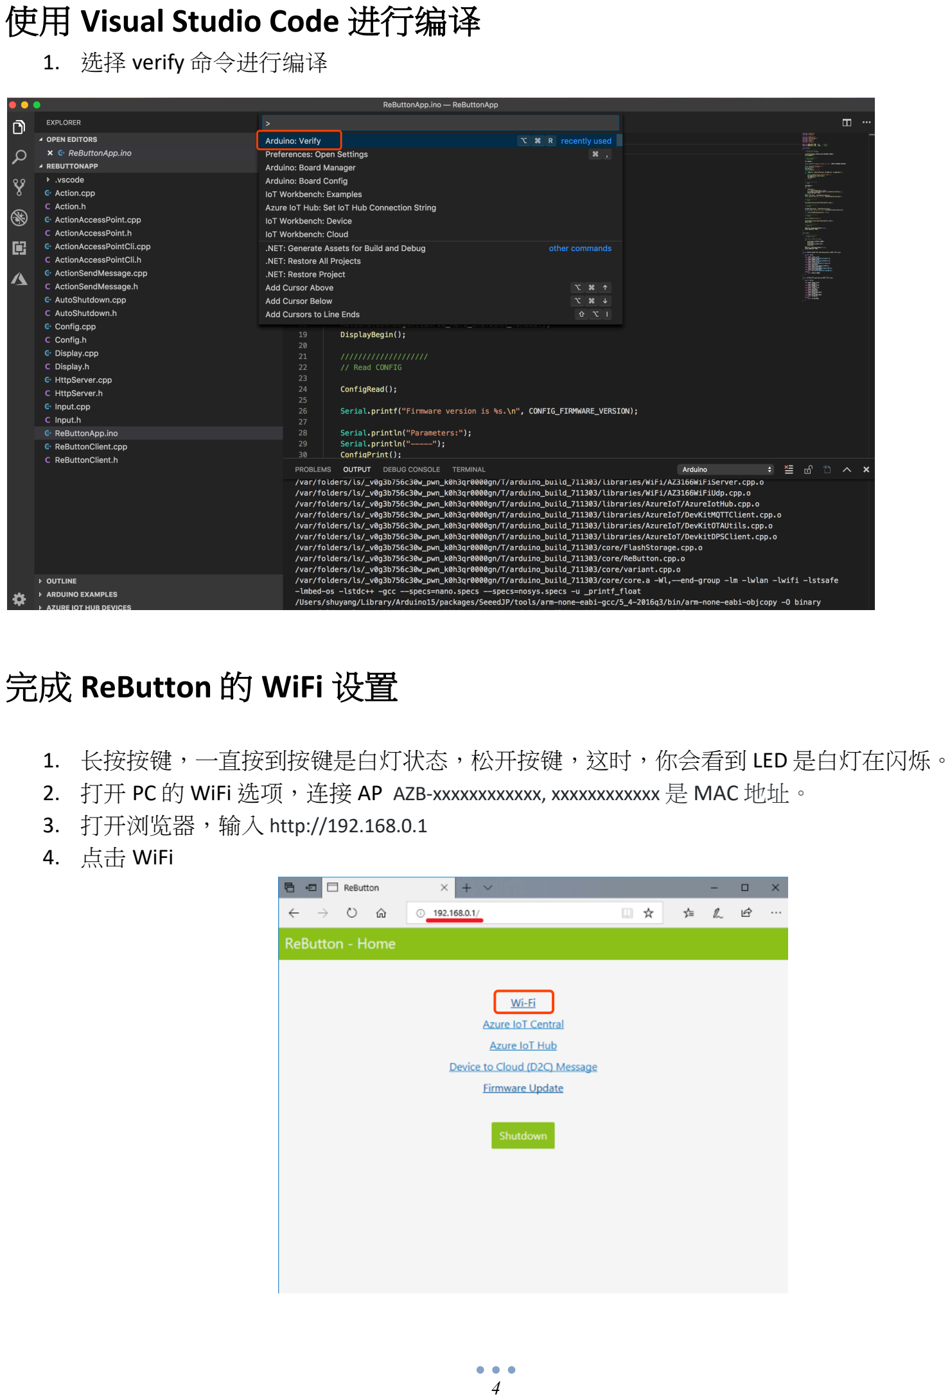
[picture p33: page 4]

1. 选择 verify 命令进行编译

## 完成 ReButton 的 WiFi 设置

1. 长按按键，一直按到按键是白灯状态，松开按键，这时，你会看到 LED 是白灯在闪烁。
2. 打开 PC 的 WiFi 选项，连接 AP AZB-xxxxxxxxxxxx, xxxxxxxxxxxx 是 MAC 地址。
3. 打开浏览器，输入 http://192.168.0.1
4. 点击 WiFi

5. 输入要连接的 WiFi 账号与密码

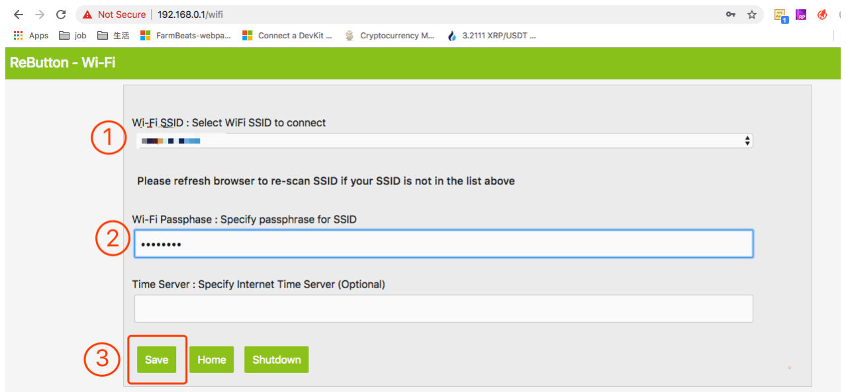
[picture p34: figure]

6. 按一下，蓝灯闪烁，证明连上了。

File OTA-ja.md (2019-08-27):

## Step 1: Azure Storageにファームウェアのバイナリファイルをアップロードしよう

[Azure CLI](https://docs.microsoft.com/ja-jp/cli/azure/)を使ってAzure Storageにファームウェアのバイナリファイルをアップロードできます。
Seeedが公開しているファームウェアを使う場合は、Step1と2の工程を省略できます。[Step3](#step-3-otaプロセス)に進んでください。

### 1.1: Azure CLIをインストールする

Azure CLIのインストール方法は[こちら](https://docs.microsoft.com/ja-jp/cli/azure/install-azure-cli)で説明しています。

[Azure StorageでのAzure CLIの使用](https://docs.microsoft.com/ja-jp/azure/storage/common/storage-azure-cli) のページはこのプロセスを遂行するのに役に立ちます。

### 1.2: 新しいStorageアカウントを作成する

Azure Storageを使うために、Storageアカウントが必要です。コンピューターとサブスクリプションの接続を設定後、新しいAzure Storageアカウントを作成できます。

```bash
az storage account create \
    --location <location> \
    --name <account_name> \
    --resource-group <resource_group> \
    --sku <account_sku>
```
例
```bash
az storage account create --location japaneast \
--name seeedkk --resource-group ReButton --sku Standard_GRS
```
IoT Hubと同じリソースグループを使えます。

### 1.3: Azureストレージアカウントを設定する
まず、使用しているアカウントから、ストレージアカウントキーを表示させます。
```bash
az storage account keys list \
    --account-name <account_name> \
    --resource-group <resource_group> \
    --output table
```
例
```bash
az storage account keys list --account-name seeedkk \
--resource-group ReButton
```
アカウントキーを入手すると、キーとアカウント名を環境変数として定義できるようになります。

```bash
export AZURE_STORAGE_ACCOUNT=<account_name>
export AZURE_STORAGE_KEY=<key>
```

### 1.4: コンテナーをつくる

Azureストレージの全てのblobはコンテナーの中になければいけません。下記のコマンドを使用して、コンテナーをつくることができます。

```bash
az storage container create --name <container_name> \
--public-access container
```

### 1.5: blobをコンテナーにアップロードする

次のコマンドで、ファームウェアのバイナリファイルをAzureストレージにアップロードできます。
```bash
az storage blob upload \
    --file <local_file_path> \
    --container-name <container_name> \
    --name <blob_name>
```
例
```bash
az storage blob upload -f ReButtonApp.1.0.bin \
--container-name rebuttonfirm --name ReButtonApp.1.0.bin
```

### 1.6: URLを取得する

[Azureポータル](https://portal.azure.com)上でアップロードしたblobのURLを確認できます。

ポータル上の`全てのサービス`の中の`ストレージアカウント`からアップロードに使ったスレージアカウントを選び、さらに`Blobs`を選んでください。

storage accounts

使用しているコンテナーの中から、アップロードしたファイル(blob)を確認できます。ファイルネームをクリックすることで、URLを参照できます。

## Step 2: CRCを計算する

CRCは私たちが提供している[generatecrc](https://github.com/SeeedJP/ReButton/tree/master/tools/generatecrc)コマンドを使うことで計算できます。

例:
```bash
$ cd generatecrc
$ ./generatecrc ../ReButtonApp.1.0.bin
========== ReButton Firmware Information ==========

Package path: ../ReButtonApp.1.0.bin
Package CRC: 0xbc3b
Package size: 641924

===================================================
```

## Step 3: OTAプロセス

**OTAは多くの電力を消費します。OTAが中断されることの無いよう、できるだけ新しい電池を使ってください。**

1. ReButtonのLEDが白く光るまでボタンを押し続け、APモードに移行させます。
   (リマインダー: アクセスポイント名は`AZB-xxxxxxxxxxxx`で、このページのURLは`http://192.168.0.1`です。)
1. ReButton - Homeを開き、`Firmware Update`をクリックします。
1. 以下の情報はこのドキュメントで解説しています。Seeedが公開しているファームウェアの情報は[こちら](https://github.com/SeeedJP/ReButton/tree/master/firmware)から確認でできます。
  - `Package URI` - Step 1.6にて
  - `Package CRC` - Step 2にて
  - `Package Size` - Step 2にて
1. **ReButtonのボタンを押している状態で、**`Update`をクリックしてください。
1. LEDが点滅を始めるまで、ReButtonのボタンを押し続けます。ReButtonはファームウェアをダウンロードし、CRCを確認し、新しいファームウェアを書き込みます。**この工程は30秒ほどかかります。**
1. LEDが白く光ったら、ボタンから手を離してください。APモードで新しいファームウェアが立ち上がった証拠です。
1. APモードの状態で、ReButtonのWi-FiとAzure connectionのセットアップをしてください。

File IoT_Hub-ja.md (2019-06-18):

# Azure IoTを始めよう
---
免責事項
このページは、ユーザーの利便性を高めるために提供されています。 Seeedは、誤りや記載漏れ、またはこの情報の使用によって得られた結果について一切責任を負いません。 このページの情報はすべて「現状のまま」提供され、完全性、正確性、適時性、またはこの情報の使用から得られる結果の保証はありません。

---

Azure IoT Hubの詳細については、[Azure IoT Hub](https://docs.microsoft.com/ja-jp/azure/iot-hub/about-iot-hub)をご覧ください。

IoT Hubの料金階層については[IoT Hub pricing](https://azure.microsoft.com/ja-jp/pricing/details/iot-hub/)のページから確認できます。

## Step 1 : Azureポータルにログインする

有効なAzureサブスクリプションが紐付いていない場合、IoT Hubを始める前に[Azureの無料アカウント](https://azure.microsoft.com/free)を作成します。

## Step 2 : Azure IoT Hubを作成する

### 2.1 : ブラウザ上で[Azure Portal](http://portal.azure.com) に移動します

### 2.2 : 左上の`リソースの作成`をクリックします。

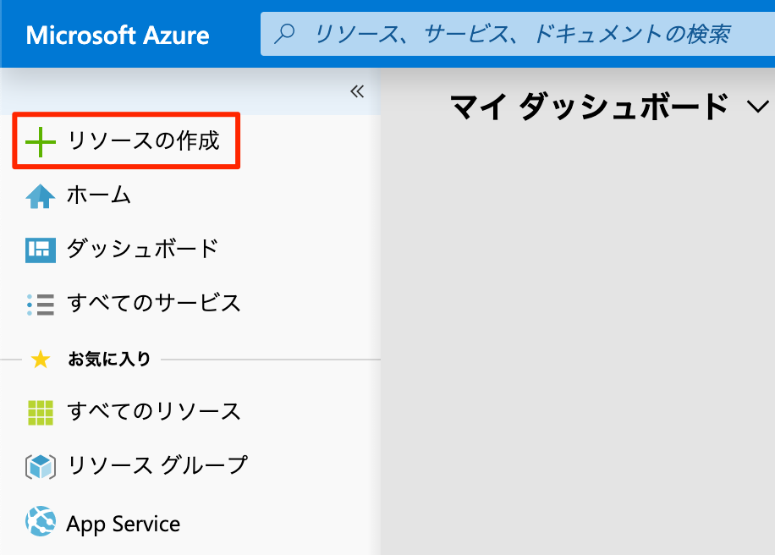
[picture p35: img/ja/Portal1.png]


### 2.3 : `モノのインターネット(IoT)`から`IoT Hub`を選びます。

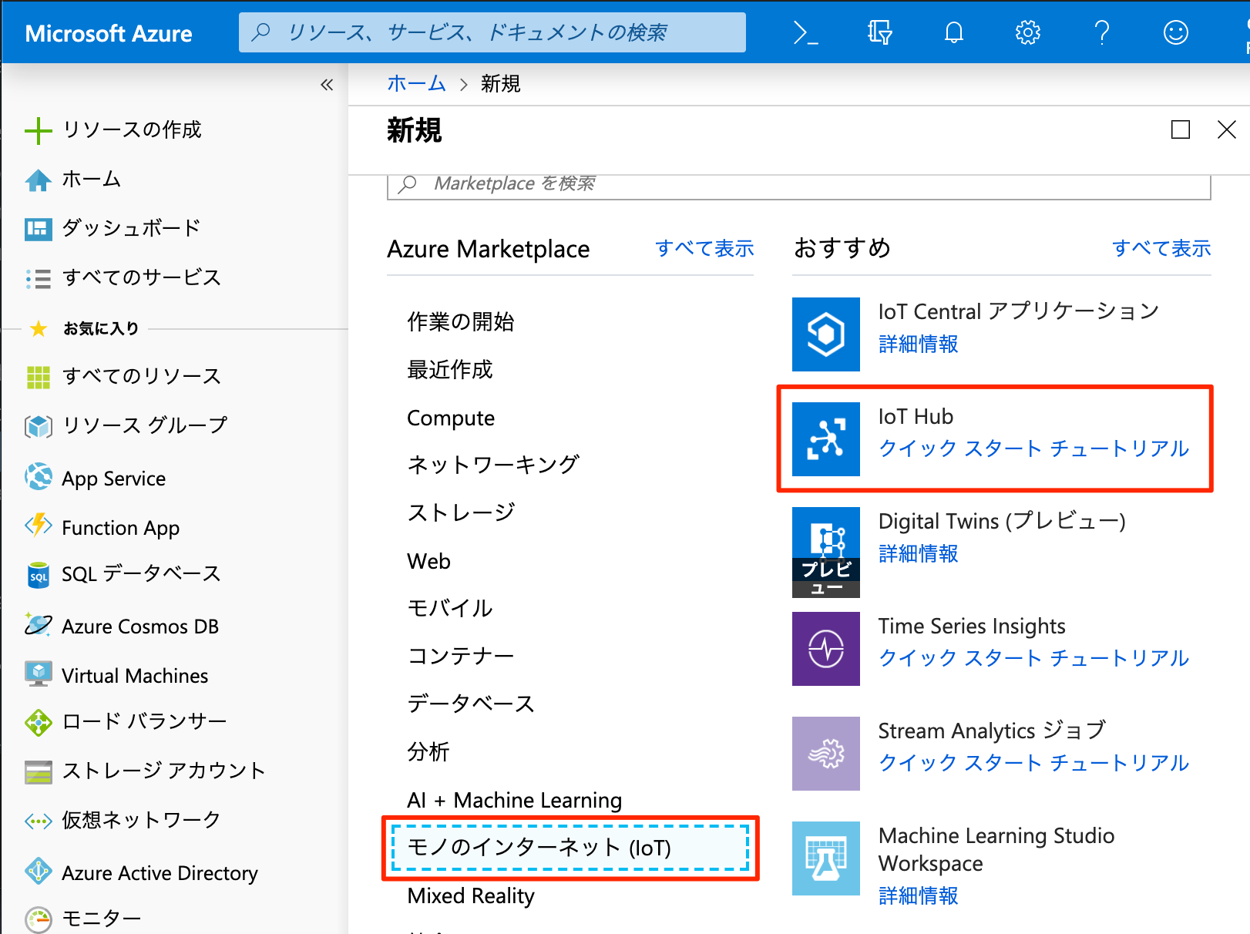
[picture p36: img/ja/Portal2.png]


### 2.4 : 必要事項を埋める

|フィールド名 | 説明  |
|---|---|
|サブスクリプション | あなたのサブスクリプションです。リストから選んでください。|
|リソースグループ |  すべてのリソースを管理するためのリソースグループです。リストの中からすでにあるグループを選ぶか、新しく作成してください。|
|リージョン | Azureのデータセンターのロケーションです。あなたの地域に近いものを選んでください。|
|IoT Hub名 |IoT Hub用にグローバルでユニークな名前をつけてください。|

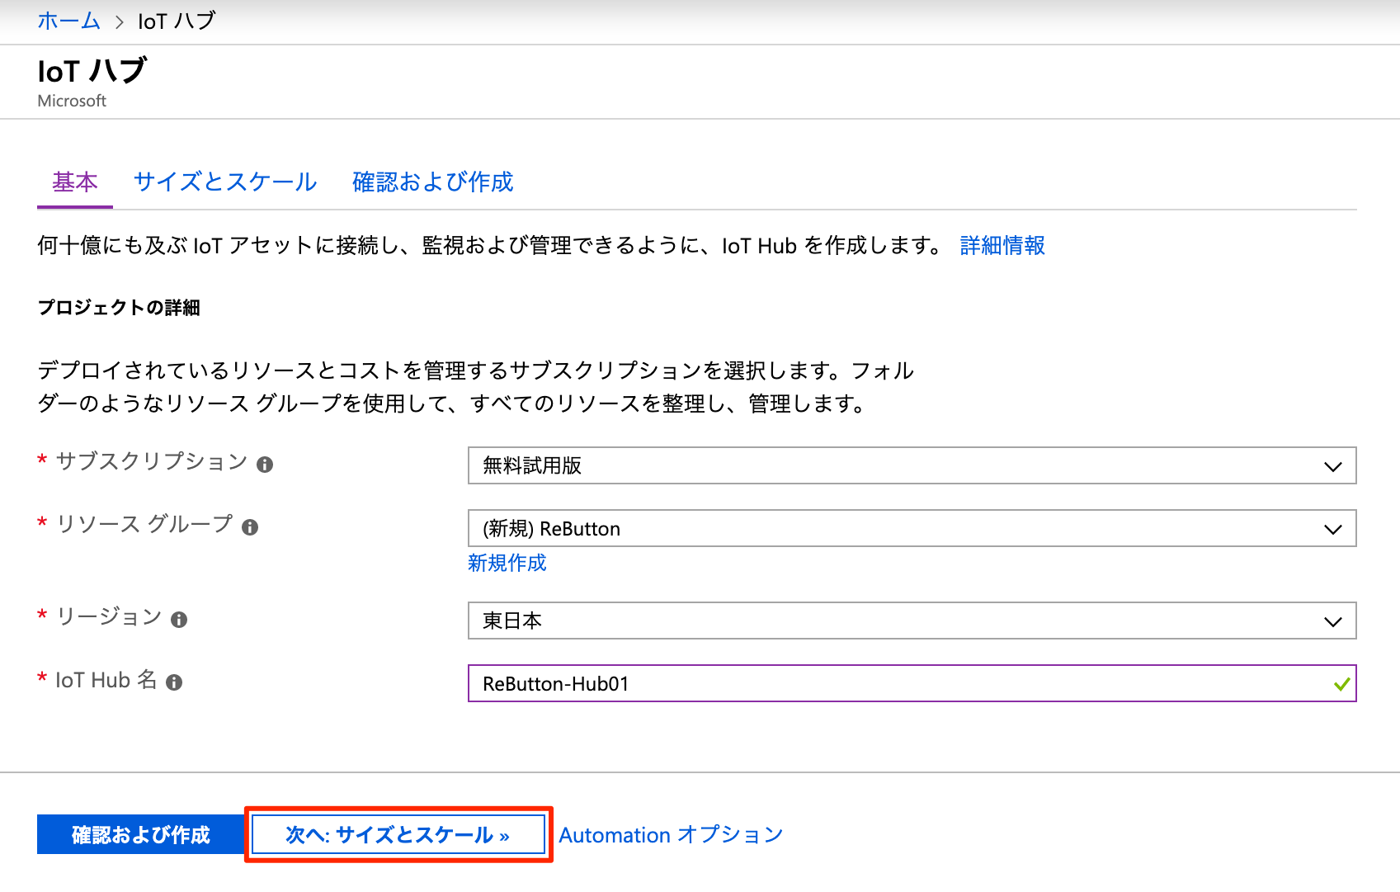
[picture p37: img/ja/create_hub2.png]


### 2.5 : サイズとスケール

サイズとスケールをクリックし、`F1:Freeレベル`を選択します。  

_※１つのサブスクリプションにつき、1つのF1:Freeレベルを選択できます。すでにF1レベルのIoT Hubがある場合は、 有料レベルのIoT Hubを登録しなれければいけません。適切なレベルの選択については[こちら](https://docs.microsoft.com/ja-jp/azure/iot-hub/iot-hub-scaling)のページをご覧ください。_

### 2.6 : `確認および作成`ボタンをクリックする

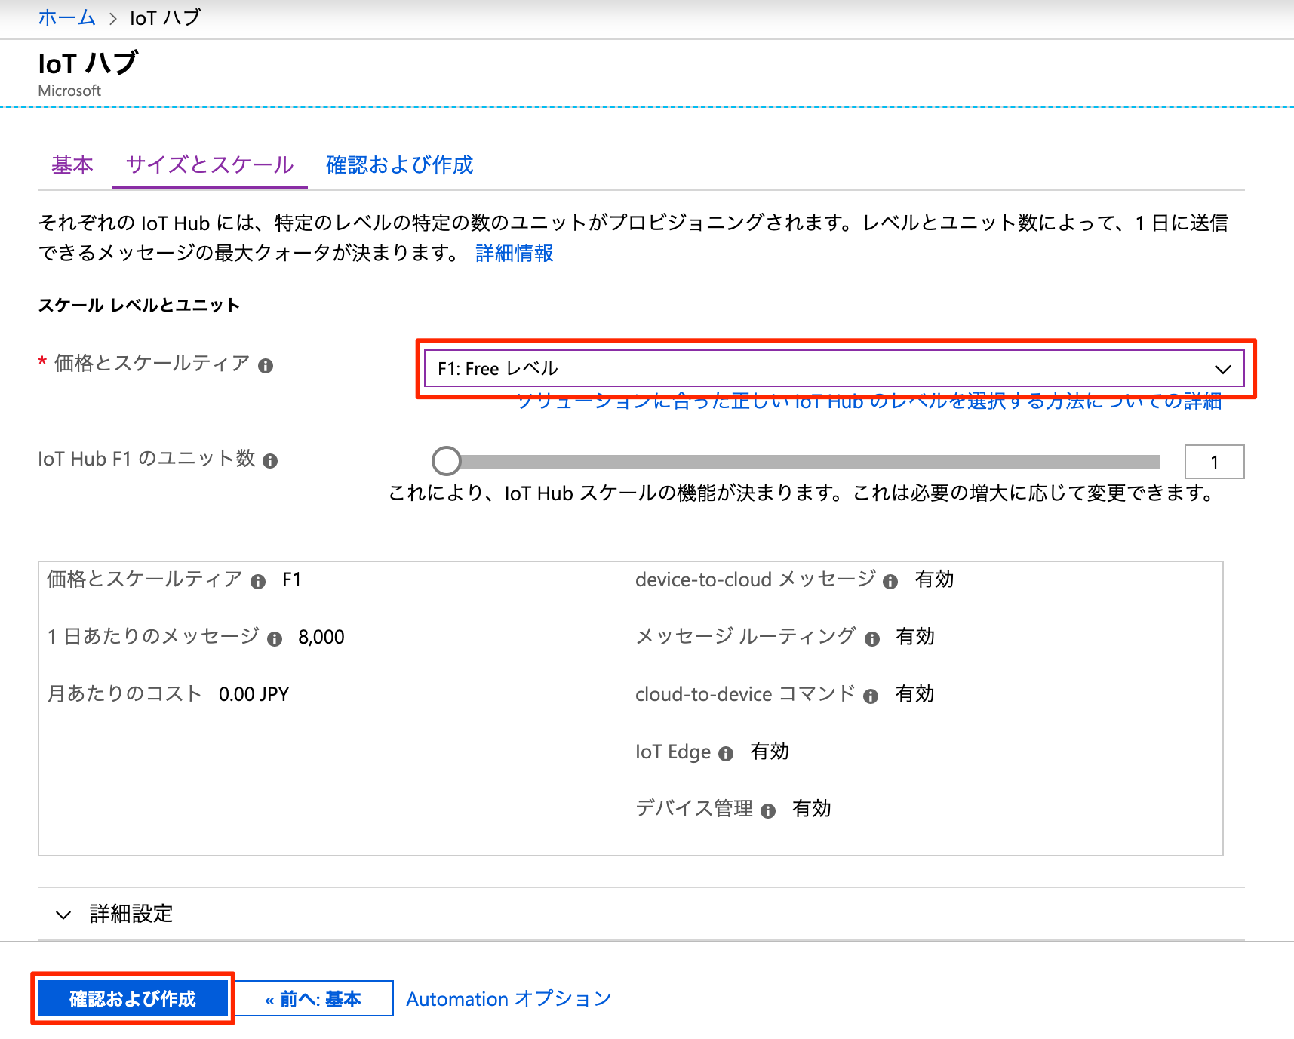
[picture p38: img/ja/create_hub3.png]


### 2.7 : Azure IoT Hubを作成する

設定を確認した後、`作成`ボタンをクリックします。

デプロイが完了するまで、少しおまちください。

## Step 3 : IoTデバイスを作成する

### 3.1 : Navigate to Azure IoT Hub instance

Azure IoT Hubがデプロイされたあと、Azure IoT Hubのリソースをクリックすると、作成されたばかりのAzure IoT Hubのインスタンスに移動します。

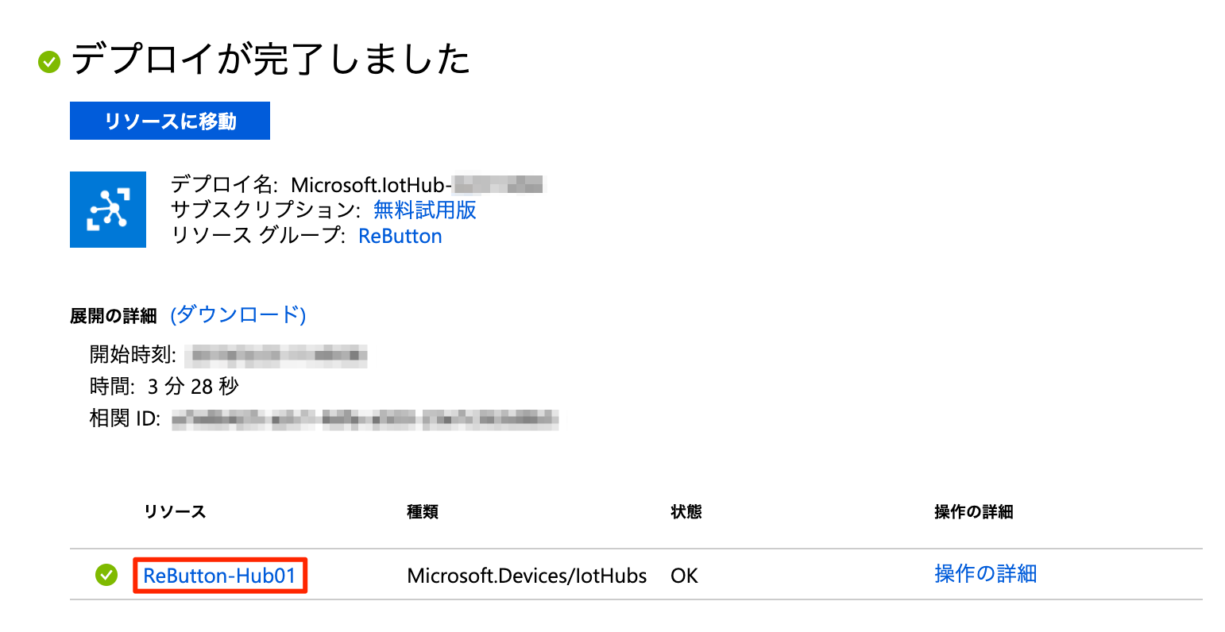
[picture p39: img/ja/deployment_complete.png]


### 3.2 : IoTデバイスの作成

`IoT デバイス`をクリックします。

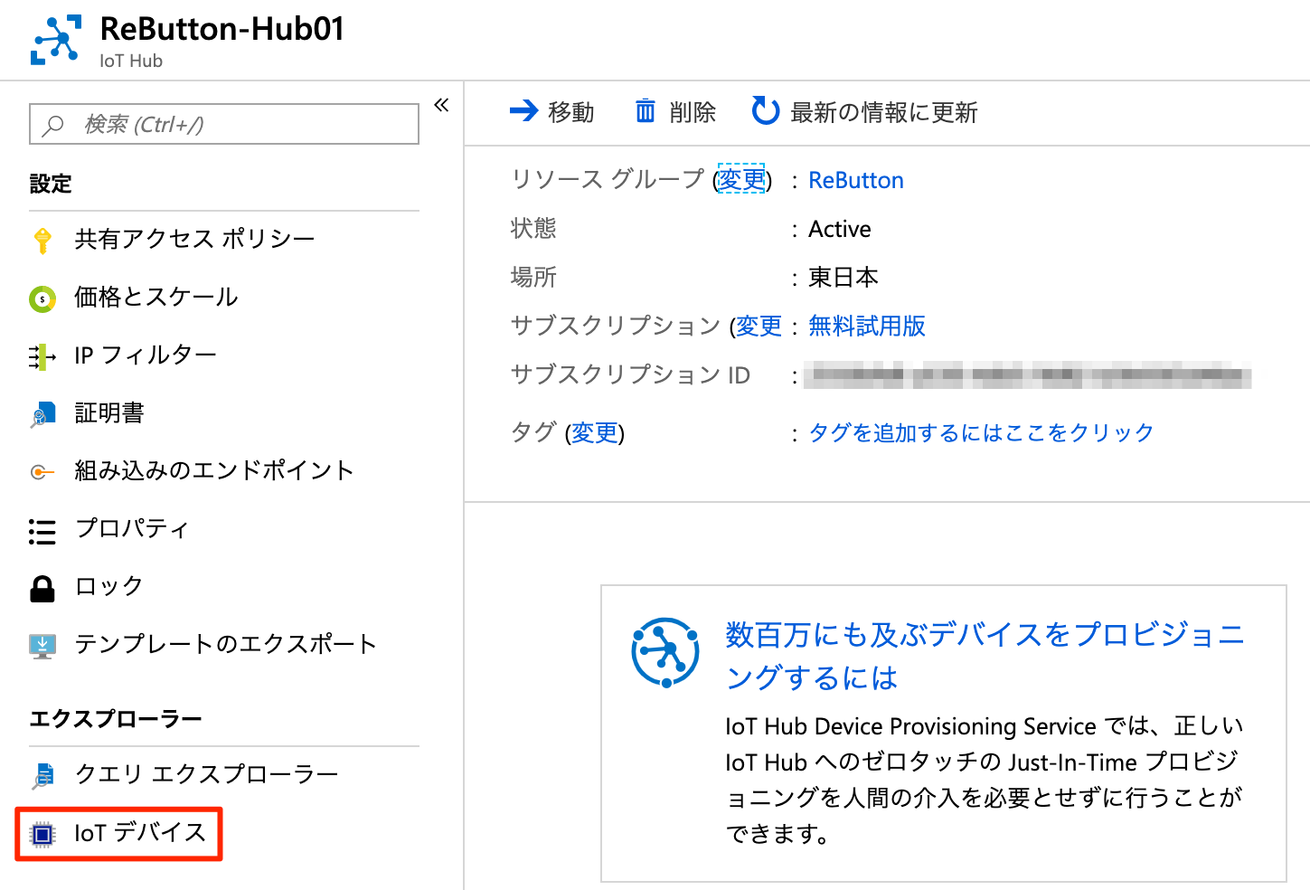
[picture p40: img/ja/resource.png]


### 3.3 : `追加`ボタンをクリックする

新しいIoTデバイスをAzure IoT Hub追加します。

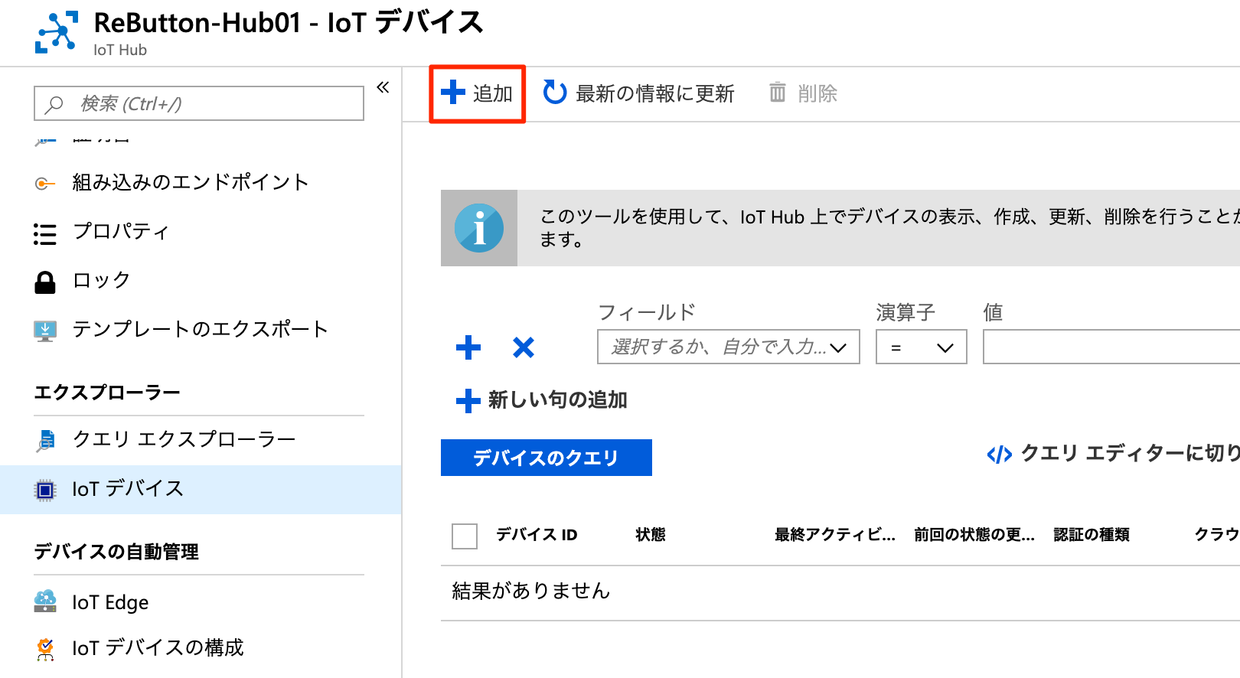
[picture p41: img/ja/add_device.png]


### 3.4 : 新しいIoTデバイスに名前をつける

ReButtonのデバイスID(名前)を設定して、`保存`をクリックします。



### 3.5 : ReButtonのために新しくIoTデバイスが作成されたことを確認します。
### 3.5 : Verify a new IoT Device for ReButton is created


## Step 4 : ReButtonとAzure IoT Hubを接続する

ReButtonとAzure IoT Hubを安全に接続するために、Connection String(接続文字列)をReButtonに保存する必要があります。

### 4.1 : デバイスの詳細ページを開く

新しく作られたIoTデバイス(例:ReButton)をクリックして、`デバイスの詳細`ページを開きます。

### 4.2 : `接続文字列`をコピーする

テキストボックスの右側にあるコピーボタンをクリックして、接続文字列(主キー)か接続文字列(センダリ キー）のどちらかをコピーしてください。



### 4.3 : 接続文字列をReButtonに保存する。

[3-1. Azure IoT Hub](README-ja.md#3-1-azure-iot-hub)を参考にしてください。

## Step 5 : 接続を認証する

[Azure CLI](https://docs.microsoft.com/en-us/cli/azure/)ツールを使用し、 ReButtonがAzure IoT Hubにメッセージを送信することを認証します。

### 5.1 : Azure CLIをインストールする。

Azure CLIのインストール方法は[こちら](https://docs.microsoft.com/ja-jp/cli/azure/install-azure-cli)で説明しています。

### 5.2 : Install IoT Extension

次のコマンドを使って、[Azure IoT extension for Azure CLI](https://github.com/Azure/azure-iot-cli-extension)をインストールします。
```
$ az extension add --name azure-cli-iot-ext
```

### 5.3 : Azureにログインする

Azure CLIがインストールできたら、次のコマンドを使ってAzureにログインします。

```
$ az login
```

Webブラウザー上でログインプロセスを完了させます。

### 5.4 : Azure IoT Hubリスト　

Azure IoT Hubの一覧を表示します。

```
$ az iot hub list
```

### 5.5 : Device to Cloud (D2C)メッセージをモニターする

RebuttonからIoT Hubに送信されるメッセージを監視するために、次のコマンドを実行します。 

_参考: [IoTHub Name]は、Step 5.4のリストコマンドで得たAzure IoT Hubインスタンスに置き換えます。_

```
$ az iot hub monitor-events -n [IoTHub Name] --properties anno sys --timeout 0
```

Azure CLIコマンドの詳細については、helpコマンドからご確認ください。 

```
$ az iot hub monitor-events --help
```

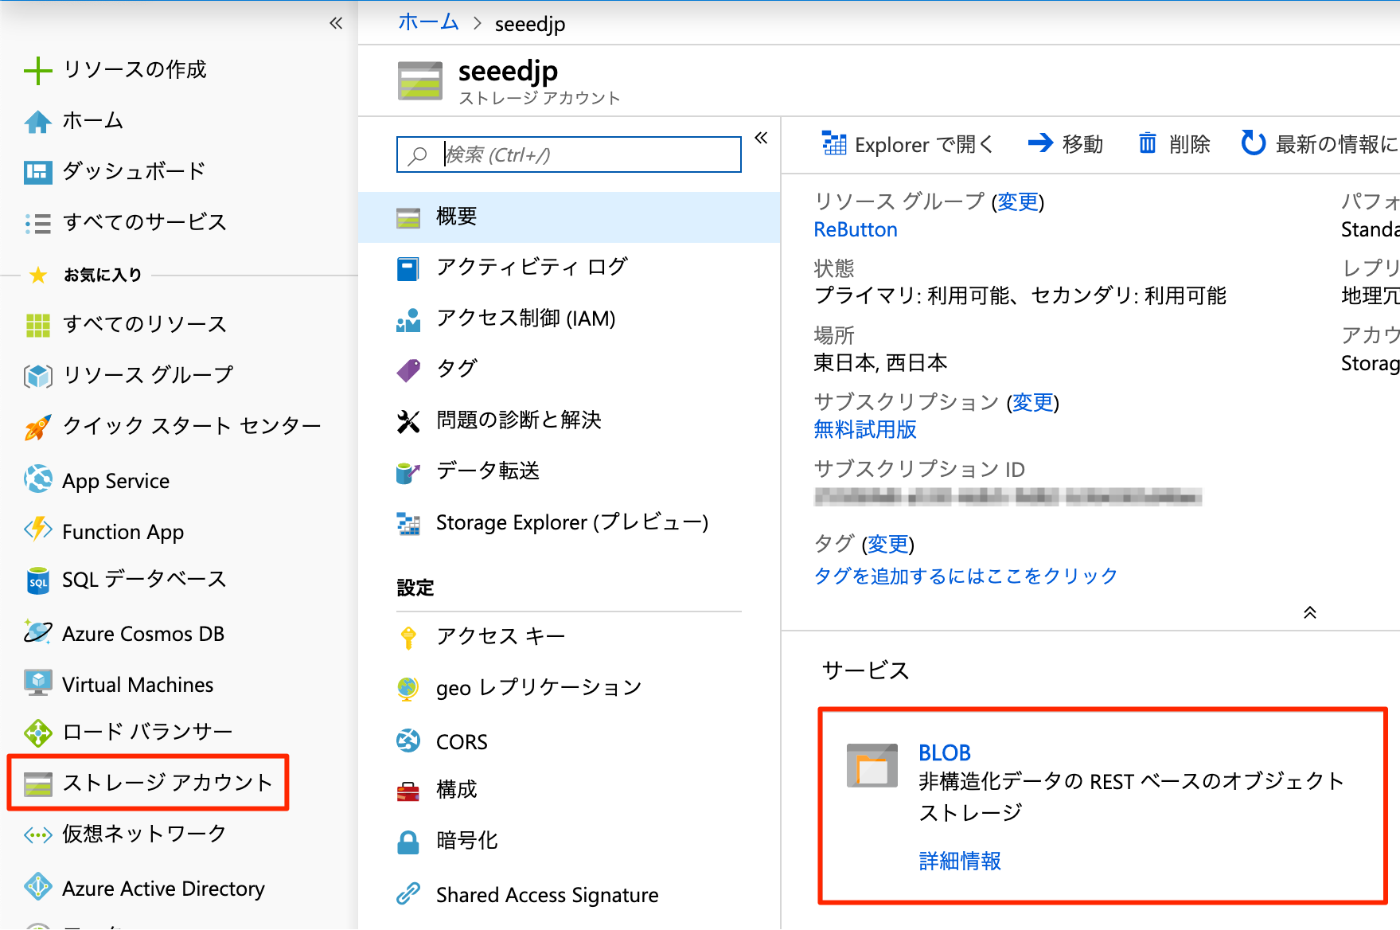
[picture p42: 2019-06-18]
img/ja/storage_accounts.png

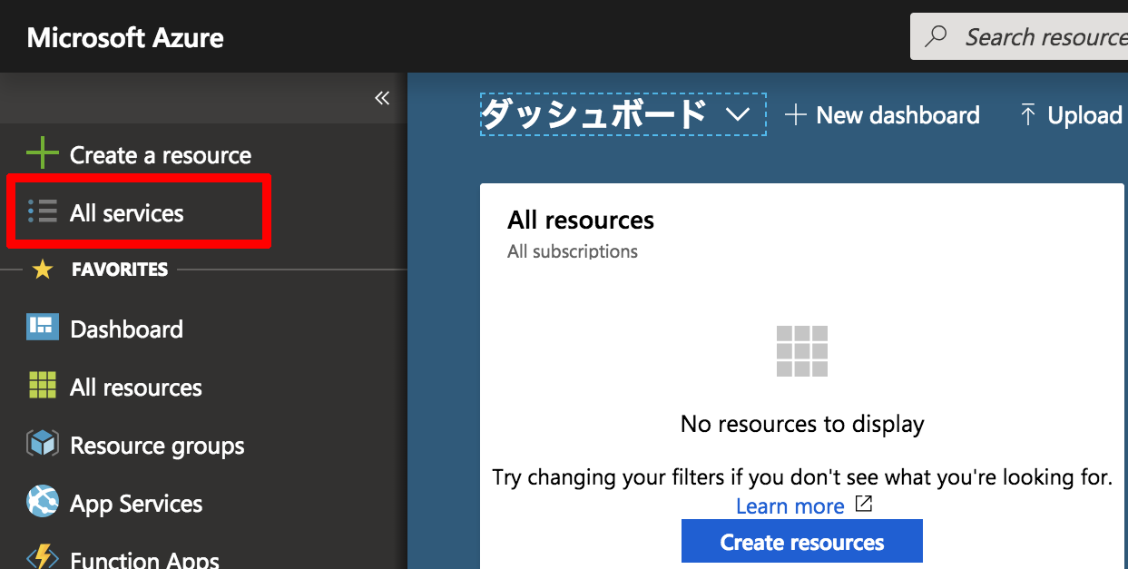
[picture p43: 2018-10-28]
img/just_login.png

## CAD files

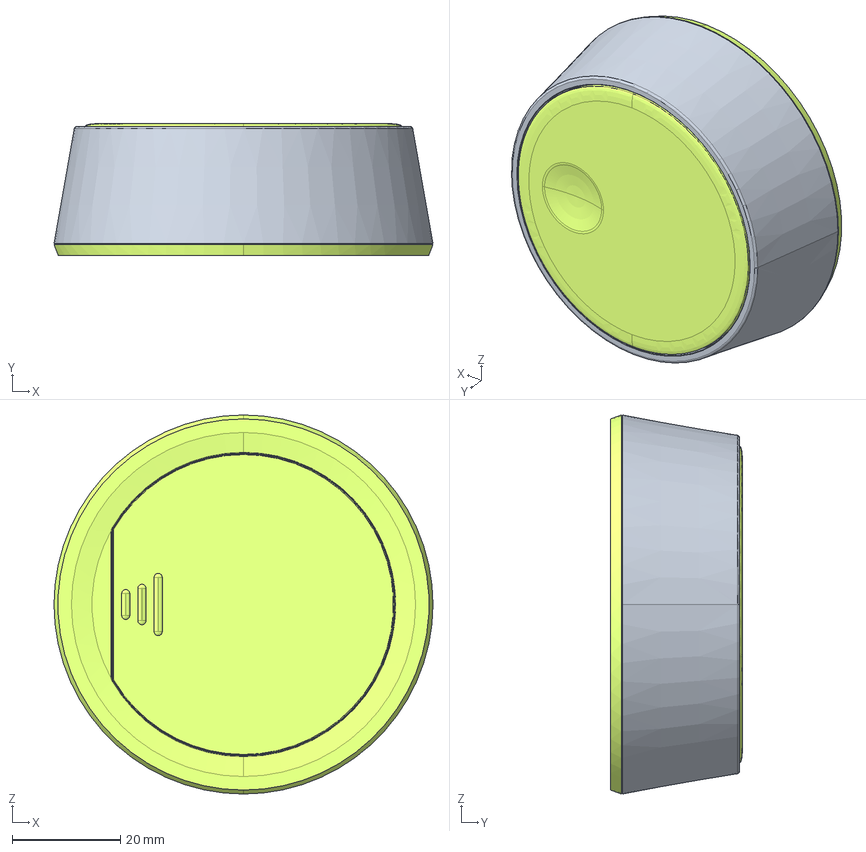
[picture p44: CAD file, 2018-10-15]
mechanicals/ReButton.stp
70.0 x 24.4 x 70.0 mm
REF_AAA_BATTERY_ANY_2_1_2_1 x 2
REF_KEYSTONE5213_ANY_2_1_2_1
REF_M2X6_THREADFORMING_96817A20 x 2
MODULE-WIFI-EMW3166_2_2_2_1
MANIFOLD_SOLID_BREP_28009_2_2_2
_LED1615_OSTB0603_ASM_2_ASM_2_2
FRAME_2_1_2_1
TOP_2_1_2_1
TRANSPARENT_SILICON_AREA_1_1_2_
BOTTOM_2_1_2_1
BATTERY_COVER_2_1_2_1
_IOT_BUTTON_ASSY_091020182030

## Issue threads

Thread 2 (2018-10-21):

Add message properties for routing

hugovoerman, 2018-10-21:
Hi Guys,

I got the ReButton to connect to IoT Hub, quite easily. In order to route/detect the messages from the ReButton a message property would come in handy. One could use this message property to route the messages to a special "ReButton" endpoint, or filter them out in ASA, or whatever. Filtering on the payload is way to risky, as messages from several devices may contain the same field(s).

Best regards,

Hugo

p.s.: I am also looking forward to the sourcecode of the firmware. With that I could have implemented the above myself.

matsujirushi, 2018-10-25:
Hi @hugovoerman ,

1. Oh I got it.
In the next version, I will add a message property at message.
Please keep open this issue.

2. We are currently working on publishing source code of default firmware. #1

hugovoerman, 2018-10-25:
Hi Takashi,

Thank you for the email.

Please make this property configurable.

Best regards,
Hugo Voerman

Sent from my phone
On Takashi Matsuoka <notifications@github.com>, 25 okt. 2018 3:35 AM wrote:

Hi @hugovoerman<https://github.com/hugovoerman> ,

  1.  Oh I got it.
In the next version, I will add a message property at message.
Please keep open this issue.

  2.  We are currently working on publishing source code of default firmware. #1<https://github.com/SeeedJP/ReButton/issues/1>

—
You are receiving this because you were mentioned.
Reply to this email directly, view it on GitHub<https://github.com/SeeedJP/ReButton/issues/2#issuecomment-432883127>, or mute the thread<https://github.com/notifications/unsubscribe-auth/AMghFTcfoxBsWC0QcO0x9gWIz92RfOgFks5uoRVsgaJpZM4Xyfx8>.

matsujirushi, 2019-01-08:
FYI
https://github.com/SeeedJP/ReButtonApp/blob/master/ReButtonClient.cpp#L235

matsujirushi, 2019-06-10:
Released. (in v1.1)
https://github.com/SeeedJP/ReButton/blob/master/firmware/readme.md

Closed 2019-06-10.

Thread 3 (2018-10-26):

Missed by a Mile

timkay, 2018-10-26:
I got a free Re-Button at the IoT in Action show today. I followed the directions to make it work, got hung up in a few places, and concluded NO WAY! The initial configuration needed to get this thing to do *anything* is way, way too complicated. I'll suspect that almost nobody with a free button from the show is going to manage to get it working.

Before I start my rant, I should mention my background, to let you know I'm not some inexperienced user. I have a Ph.D. in Computer Science. I have been using AWS for more than a decade. I wrote the first popular command line tool for AWS, back when Amazon expected you to write your own code to do every bit of configuration. I recently have been using GCP successfully. I've never used Azure.

The fact that I've never used Azure shouldn't disqualify me from trying the ReButton, unless the project targets only people who have experience with Azure IoT. In concept, lots of people should be able to find ReButton really useful. I don't think they will.

Here is a list of observations/issues:

* It's easy enough to get it into AP mode. My desktop is hard wired, so I can't use it to configure the button. Instead I used my Android phone.
* The button serves pages that render terribly on a phone. They maintain 1-inch margins, which leaves about 1/2 inch  down the middle of the screen for content.
* I entered my WiFi credentials as instructed then Shutdown. The button blinks a blue pattern (not documented) then blinks red, which strikes me as an error, but again not documented.
* The instructions say to put the IoT Device Connection String in the appropriate place. They don't say if I need to go back into AP mode to do that. Do I, or can I connect to the ReButton while it's connected to my WiFi? I couldn't find the device on my WiFi, probably because it turns off quickly. I added the string via AP mode, and they seem to stick.
* It's hard to do these configurations now: The device turns off very quickly after entering AP mode. (Blinks white for a while then off, before I have a chance to connect my phone and do the configuration.)
* I followed the instructions to create Azure IoT Hub + IoT Device. The instructions skipped over a few important steps, such as creating a Hub before you can create a Device. And be careful: the default choice for creating a Hub comes with a $25/mo charge, whereas there is a free option that you can choose.
* The instructions mention "Azure IoT Hub" and "Azure IoT Central". Do I need to do both? Or are they two alternative ways to configure? I suspect it's two different ones, but the instructions don't say so.
* I managed to create a Hub and a Device. I got the Connection String into the device. But that's as far as I got. Do I need to do the Central thing too? Or can I get some activity using just IoT Hub? I started to do a tutorial that talks me through how to use Hub, but I didn't get very far. It's *way* too much of a commitment at this stage of evaluating the ReButton.

At this point, realizing I'd need another hour or two, I deleted my storage and hub and then closed the Azure window.

Seriously?

If you want to have a wider audience reach some measure of success, they need to have a successful experience after adding WiFi credentials. Maybe have the devices talk to some pre-configured service by default. I would enter my WiFi credentials, then go to rebutton.com, type in a serial number, and then see my device doing something.

I could build that for you. Let me know if you are interested.

ytsuboi, 2018-10-26:
@timkay Thank you for your feedback! It helps us to see where we need to improve.

Hi007, 2019-08-04:
Hi there,
I'll echo some of my observations that the instructions require some work. I haven't been successful in configuring the ReButton.
I see that configuring the REButton through AP mode to Wifi is easy. After that using the IoT Hub or IoT  central are the choices. I wanted to use IoT hub the instruction in 3.1 stops at sticking in the IoT hub connection string. It does not mention how to create the Device in IoT Hub.
And finally some info on testing would be useful.

Will be happy to help test the instructions so that they are helpful.

Closed 2018-10-26.

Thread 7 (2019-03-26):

Seeed ReButton doesn't go into Wifi AP mode

Robbo1976, 2019-03-26:
I'm a newbie, so hope I'm in the right location to ask this question: I received a Seeed Rebutton at IOT event recently and trying to connect to it via Wifi. Unfortunately the button doesn't boot into AP mode. Instructions say 'Hold button until RGB LED turns into White. RGB LED will start with Blue, Yellow, Cyan, then White. This will take about 10 seconds. Then:
Release button and confirm ReButton is in AP mode. When ReButton successfully boots into AP Mode, RGB LED will blink in White.  I do get the 'white' LED, then let the button go, it flashes twice, but doesn't seems to boot in AP mode, nor show the AZB-..... Access point. Any tips? Can't find it on Seeed website or googling it. Is there anyway to rest the device? There's only 1 jumper on the button, on the left pin and not connected to the right pin. If I connect the jumper to both pins the LED starts flashing orange, but no AP ....   Thanks for your help,

matsujirushi, 2019-03-26:
Hi,
You don't need to connect jumper.
Can you see that LED changing BLUE->YELLOW->CYAN->WHITE?
https://youtu.be/EZWZbriy8e4?t=1715

Robbo1976, 2019-03-26:
Hi Takashi, thanks for your reply.
It is changing color but the white is not really white, but that’s the 4th color, then letting go of the button I see it flash twice, but no Wifi AP appears on my phone or on my laptop, so it doesn’t seem to go into AP mode.
In your video, I can clearly see the LED continues to flash white, where mine only flashes twice and then stops, so it doesn't go into AP mode.
Maybe my Seeed button is different (cover is also blue instead of green, but that could be just cosmetic).

Thanks for your help.

Attachments area

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

matsujirushi, 2019-04-25:
Hi,
I checked.
ReButton need 3V/400mA from battery to go to AP mode.
Could you change to new battery?

Robbo1976, 2019-04-26:
Brilliant, that was the solution, I never thought of that as the LEDs were
responding.
After changing the battery with brand new ones, the access point enables
and I can connect and configure the button.
What use cases have you come across for the button?

Thanks,
Robin

On Thu, 25 Apr 2019 at 18:57, Takashi Matsuoka <notifications@github.com>
wrote:

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

Closed 2019-06-10.

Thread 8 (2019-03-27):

Please describe purpose of jumper

JuergenKosel, 2019-03-27:
Hello,

please describe the purpose of the jumper.

matsujirushi, 2019-03-28:
Hi,

Jumper has two functions.
1. ReButton keep power supply on. It use when firmware development.
2. Reset parameters (by default firmware).
  https://github.com/SeeedJP/ReButtonApp/blob/master/ReButtonApp.ino#L36
  https://github.com/SeeedJP/ReButtonApp/blob/master/Config.cpp#L34

Closed 2019-03-28.

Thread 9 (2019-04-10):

[Newbie] Question about click velocity

Defkon1, 2019-04-10:
Hello everybody!
I configured my ReButton to send D2C to IoT Hub and set VSCode listening to the message queue.

If I click the button nothing happens (neither if I double click or triple click); if I keep pressed for at least 1 second the click is performed.

Is this the intended behaviour (more sort of a short-press rather than a click)?

Defkon1, 2019-04-10:
Probably I found the reason by myself:

`static const int InputWaitForClickTime   = 1000;  // [msec.]
static const int InputLongPressTime      = 3000;  // [msec.]
static const int InputSuperLongPressTime = 6000;  // [msec.]
static const int InputUltraLongPressTime = 10000; // [msec.]`

should I lower the first one and reflash the ReButton to achieve a faster click recognition, right?

ytsuboi, 2019-04-10:
Hi @Defkon1,
The button pressing start supplying power to the electronics and starts running code. About 0.3 sec after MCU start running, MCU start to keep power supply. This means, if you take your finger in this 0.3 sec, MCU can't keep the power supply and electronics will be turned off.
So, please press and hold the button for more than 0.5 sec.

Defkon1, 2019-04-10:
thanks for the clarification!

Closed 2019-04-10.

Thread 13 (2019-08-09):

Not seeing reported values in Azure IoT Device Twin

bradboren, 2019-08-09:
I purchased a ReButton and connected to WiFi and my IoT Hub device (using section 3.1 of the instructions).  When I press the button it connects to the WiFi and seems to send a message to Azure IoT.

When I look at my device twin I expect to see actionNum and message values in the reported section.  Instead I see:

"reported": {
      "customMessageEnable": {
        "value": false
      },
      "$metadata": {
        "$lastUpdated": "2019-08-09T19:28:25.0391204Z",
        "customMessageEnable": {
          "$lastUpdated": "2019-08-09T19:28:25.0391204Z",
          "value": {
            "$lastUpdated": "2019-08-09T19:28:25.0391204Z"
          }
        }
      },
      "$version": 14
    }

The date/time seems to update in the $lastUpdated but no other info.  Any suggestions on what I might be doing wrong?  I am excited to get this working.

Thank you!

matsujirushi, 2019-08-27:
Hi @bradboren ,
ReButton update the reported properties is customMessageEnable only. [code](https://github.com/SeeedJP/ReButton/tree/master/firmware)
So actionNum and message value is into D2C message. [code](https://github.com/SeeedJP/ReButtonApp/blob/master/ActionSendMessage.cpp#L65-L66)

bradboren, 2019-08-30:
I think I am getting it now.

The Rebutton will only have a "customMessageEnabled" value in the reported properties (which is stored in the device twin).  The D2C message that is sent (and not shown in the Device Twin) is where the actionNum and other message data is sent.

That is a bit of a challenge on my side as my tool is looking at device twin info.  But I think I understand better what is happening.

Thank you again for the help!  I still hope this works but need to turn to some of our developers to see if we can consume the message data.

Closed 2019-09-27.

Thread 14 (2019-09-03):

OTA update fails

AieatAssam, 2019-09-03:
I have ReButton version 1.0 and can see that firmware is currently on 1.4 and has added support for custom messages. Following update instructions on https://github.com/SeeedJP/ReButton/blob/master/OTA.md I wasn't getting anywhere. So I connected my trusty USB-UART to the debu port to try to see what is going on (baud rate should be 115200, by the way - doesn't seem to be documented, so I had to dig into arduino board source for this).

Results are as follows:
```
packageURI = https://seeedkk.blob.core.windows.net/rebuttonfirm/ReButtonApp.1.4.bin
packageCRC = 0xdaeb
packageSize = 680740
Connect WiFi...
Time from pool.ntp.org, now is (UTC): Thu Jan  1 00:00:06 1970

Connected WiFi.
Download firmware...
>>> Failed to send telemetry data: Http fault.
Downloaded firmware.
inPackageCRC = 0xdaeb
inPackageSize = 680740
dlPackageCRC = 0x02
dlPackageSize = -1

```

Looking into the board files and OTAFirmwareUpdate.cpp, it seems that size -1 occurs when failing to write to flash. Just in case, to eliminate SSL being the issue, I created Azure blob container without secure access enabled and tried OTA update without SSL. Results are the same.

Is there a step I am missing to make flash writeable for OTA updates? Or is my hardware faulty? I only received it yesterday and ordered direct from Seeed, so was hoping it would have up to date firmware to begin with (no such luck).
Are there any other ways of uploading firmware? i.e. do you have bootloader mode that can take it via UART? Although doubt it would do much if flash itself is non-writeable (line setting body length to -1 is the relevant one):
```C++
static void getFwCallback(const char *at, size_t length)
{
    if (at == NULL || length == 0 || body_length < 0)
    {
        return;
    }
    // Write to external flash
    if (MicoFlashWrite((mico_partition_t)MICO_PARTITION_OTA_TEMP, &flashIdx, (uint8_t *)at, length) == kNoErr)
    {
        CRC16_Update(&contexCRC16, at, length);
        body_length += length;
    }
    else
    {
        body_length = -1;
    }
}

int OTADownloadFirmware(const char *url, uint16_t * crc16Checksum, const char* ssl_ca_pem)
{
    uint16_t checkSum = 0;
    flashIdx = 0;
    body_length = 0;
    CRC16_Init(&contexCRC16);

    HTTPClient client = ssl_ca_pem ? HTTPClient(ssl_ca_pem, HTTP_GET, url, getFwCallback) : HTTPClient(HTTP_GET, url, getFwCallback);
    const Http_Response *response = client.send(NULL, 0);
    if (response->status_code != 200)
    {
        // Download failed
        return -1;
    }
    else if (body_length < 0)
    {
        // External flash accessing issue
        return -2;
    }
    else if (body_length == 0)
    {
        // Empty
        return 0;
    }

    // Finalize the CRC16 value
    CRC16_Final(&contexCRC16, &checkSum);

    if (crc16Checksum)
    {
        *crc16Checksum = checkSum;
    }

    return body_length;
}
```

ytsuboi, 2019-09-03:
Hi @AieatAssam ,
As on the OTA documentation Step 1&2, you need to store the binary on Azure blob container.
The debug log you attached pointed our github URL.

AieatAssam, 2019-09-03:
Actually, my log points to your blob at seeedkk.blob.core.windows.net

But I have also tried with my own blob storage accounts - one with and one without SSL and both times got the same result. Exactly the same size -1.

matsujirushi, 2019-09-04:
Hi @AieatAssam ,

> Time from pool.ntp.org, now is (UTC): Thu Jan  1 00:00:06 1970

I think your ReButton failed time sync.
Could you change time server in Wi-Fi page?

**v1.0 -> v1.4 log:**
```
packageURI = https://seeedkk.blob.core.windows.net/rebuttonfirm/ReButtonApp.1.4.bin
packageCRC = 0xdaeb
packageSize = 680740
Connect WiFi...
Time from pool.ntp.org, now is (UTC): Wed Sep  4 00:34:45 2019

Connected WiFi.
Download firmware...
Downloaded firmware.
inPackageCRC = 0xdaeb
inPackageSize = 680740
dlPackageCRC = 0xdaeb
dlPackageSize = 680740
Switch firmware...
Switched firmware.
```

AieatAssam, 2019-09-04:
My ntp is set to 0.pool.ntp.org in the WiFi settings page and yet during firmware update it seems to be going to pool.ntp.org (note no zero).
Should time sync failing even be an issue without SSL? Normally it will affect certificate validation but with non ssl this shouldn’t be an issue.
I’ll still try alternative ntp servers to see if this helps. Will post back results afterwards.

AieatAssam, 2019-09-04:
I have just changed my ntp to time.google.com in wifi settings, however, it still tries to sync up with pool.ntp.org. I tracked this down to SystemTime.cpp under cores\arduino\system where a hardcoded list of ntp servers is being used. Looking at the code, it seems as if the response from ntp client indicates success when it clearly isn't.
My suspicion is that our corporate network security is causing ntp to time out (it's very time sensitive), so I tethered to my mobile phone. Lo and behold, the update went through and I am now on 1.4

Closed 2019-09-06.

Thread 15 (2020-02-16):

Blue blinking LED - Question

jonmikeli, 2020-02-16:
Hi,

Every time I push the button (no matter the number of clicks), the blue LED blinks for approximately 30s and I do not receive any data.
I guess there is a connectivity issue but I wanted to check what is the meaning of the blue blinking LED. Where could I find that information?
Any other LED "codes" we should know?

Thanks.

jonmikeli, 2020-02-16:
Message reception issues solved after a firmware update.
So, I will close the issue.

Closed 2020-02-16.

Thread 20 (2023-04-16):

Unable to install Rebutton board pack in Arudino IDE

homemadestea58, 2023-04-16:
System:
- Ubuntu 20.04 running in WSL (Windows Subsystem for Linux)
- Arduino IDE 2.0.4
- Host: Lenovo AMD Ryzen 5500U

Issue:
I am not able to install the SeedJP ReButton Board package in my Arduino IDE. Each time I try to install it, the IDE throws this error:
`Error: 13 INTERNAL: Cannot install tool SeeedJP:arm-none-eabi-gcc@5_4-2016q3-seeed: testing local archive integrity: testing archive size: fetched archive size differs from size specified in index: 51395093 != 0`

I have managed to install the Pack on my Windows PC directly, but both my Raspberry Pi and Ubuntu WSL have thrown this error.

Does anyone know how to fix this, or even how to install the packages manually?

Logs:
`Downloading packages
SeeedJP:arm-none-eabi-gcc@5_4-2016q3-seeed
SeeedJP:openocd@0.11.0-1-xpack
SeeedJP:SeeedJP_ReButton@2.1
Installing SeeedJP:arm-none-eabi-gcc@5_4-2016q3-seeed
Failed to install platform: SeeedJP:SeeedJP_ReButton.
Error: 13 INTERNAL: Cannot install tool SeeedJP:arm-none-eabi-gcc@5_4-2016q3-seeed: testing local archive integrity: testing archive size: fetched archive size differs from size specified in index: 51395093 != 0`

My aim is to try and replace the Azure code with a simple HTTP request to my local Home Assistant instance so any help on that would also be appreciated.

matsujirushi, 2023-04-17:
Thank you for the report.

I fixed `https://www.seeed.co.jp/package_SeeedJP_index.json`. You can download and install the ReButton platform on Linux.
However, it has been confirmed that some compilation problems occur.

We compile ReButton's firmware in Windows environment. Therefore, it is strongly recommended to use the Windows environment.

homemadestea58, 2023-04-17:
@matsujirushi Thank you for that.
I also wanted to ask, if I want to change the ReButton to use simple http requests instead of Azure for each button click, eg. for Home Assistant, what network library would I use?

Would I just use one of the built in Arduino ones, the ones in the IDE, or do I use something else like Winsock2?

matsujirushi, 2023-04-17:
@homemadestea58
I created new issue. #22

Closed 2023-04-17.

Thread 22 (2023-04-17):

to use simple http requests

matsujirushi, 2023-04-17:
I also wanted to ask, if I want to change the ReButton to use simple http requests instead of Azure for each button click, eg. for Home Assistant, what network library would I use?

Would I just use one of the built in Arduino ones, the ones in the IDE, or do I use something else like Winsock2?

_Originally posted by @homemadestea58 in https://github.com/SeeedJP/ReButton/issues/20#issuecomment-1510584996_

matsujirushi, 2023-04-17:
The ReButton platform is based on the [AZ3166 IoT DevKit platform](https://github.com/microsoft/devkit-sdk).
I think you can use the HTTPClient class.

https://microsoft.github.io/azure-iot-developer-kit/docs/apis/http-client/

homemadestea58, 2023-04-17:
Thanks @matsujirushi. I'll check this out.

Closed 2023-04-17.

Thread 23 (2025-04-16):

Can't Flash Device

jpersofsky, 2025-04-16:
I'm trying to flash the ReButton using openocd and a Raspberry Pi 3B+.  I also tried using a Mac and ST-Link v2.  No luck.  The error I'm getting is: Debug: 147 16 stlink_usb.c:1086 stlink_usb_error_check(): STLINK_JTAG_GET_IDCODE_ERROR
Error: 148 16 stlink_usb.c:3748 stlink_open(): init mode failed (unable to connect to the target).  The error seems similar when I use the RPi with GPIO.

I tested the voltage on the GPIO pins using pinctrl .  Everything seems to be connected properly.

matsujirushi, 2025-04-16:
Hi @jpersofsky ,
Could you give me detailed reproduction steps?

matsujirushi, 2025-04-19:
> 3. Hold button until blue light comes on

I think there is a lack of time to push button.
Could you please hold it down until the rewrite is complete in openocd?

jpersofsky, 2025-04-19:
it was a wiring issue.  the docs clearly say the diagram is of the PAD (not the cable) - and I reversed it.  sorry about that.

Closed 2025-04-19.

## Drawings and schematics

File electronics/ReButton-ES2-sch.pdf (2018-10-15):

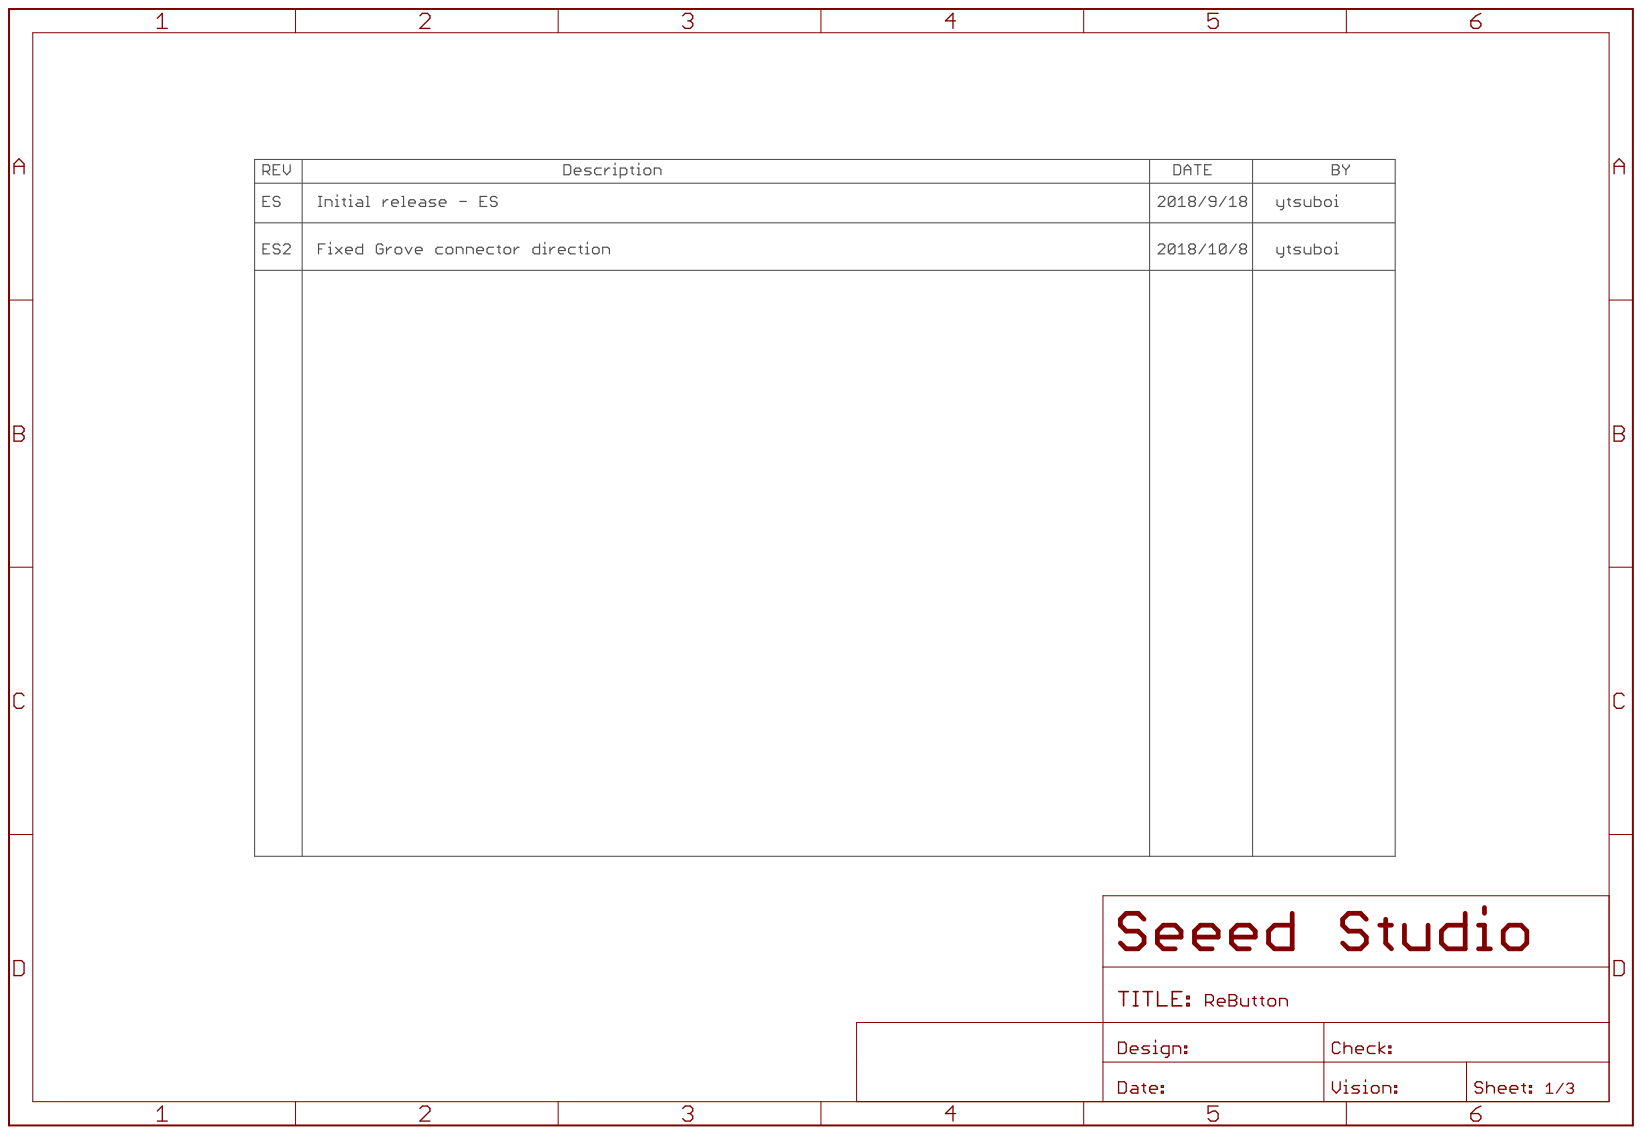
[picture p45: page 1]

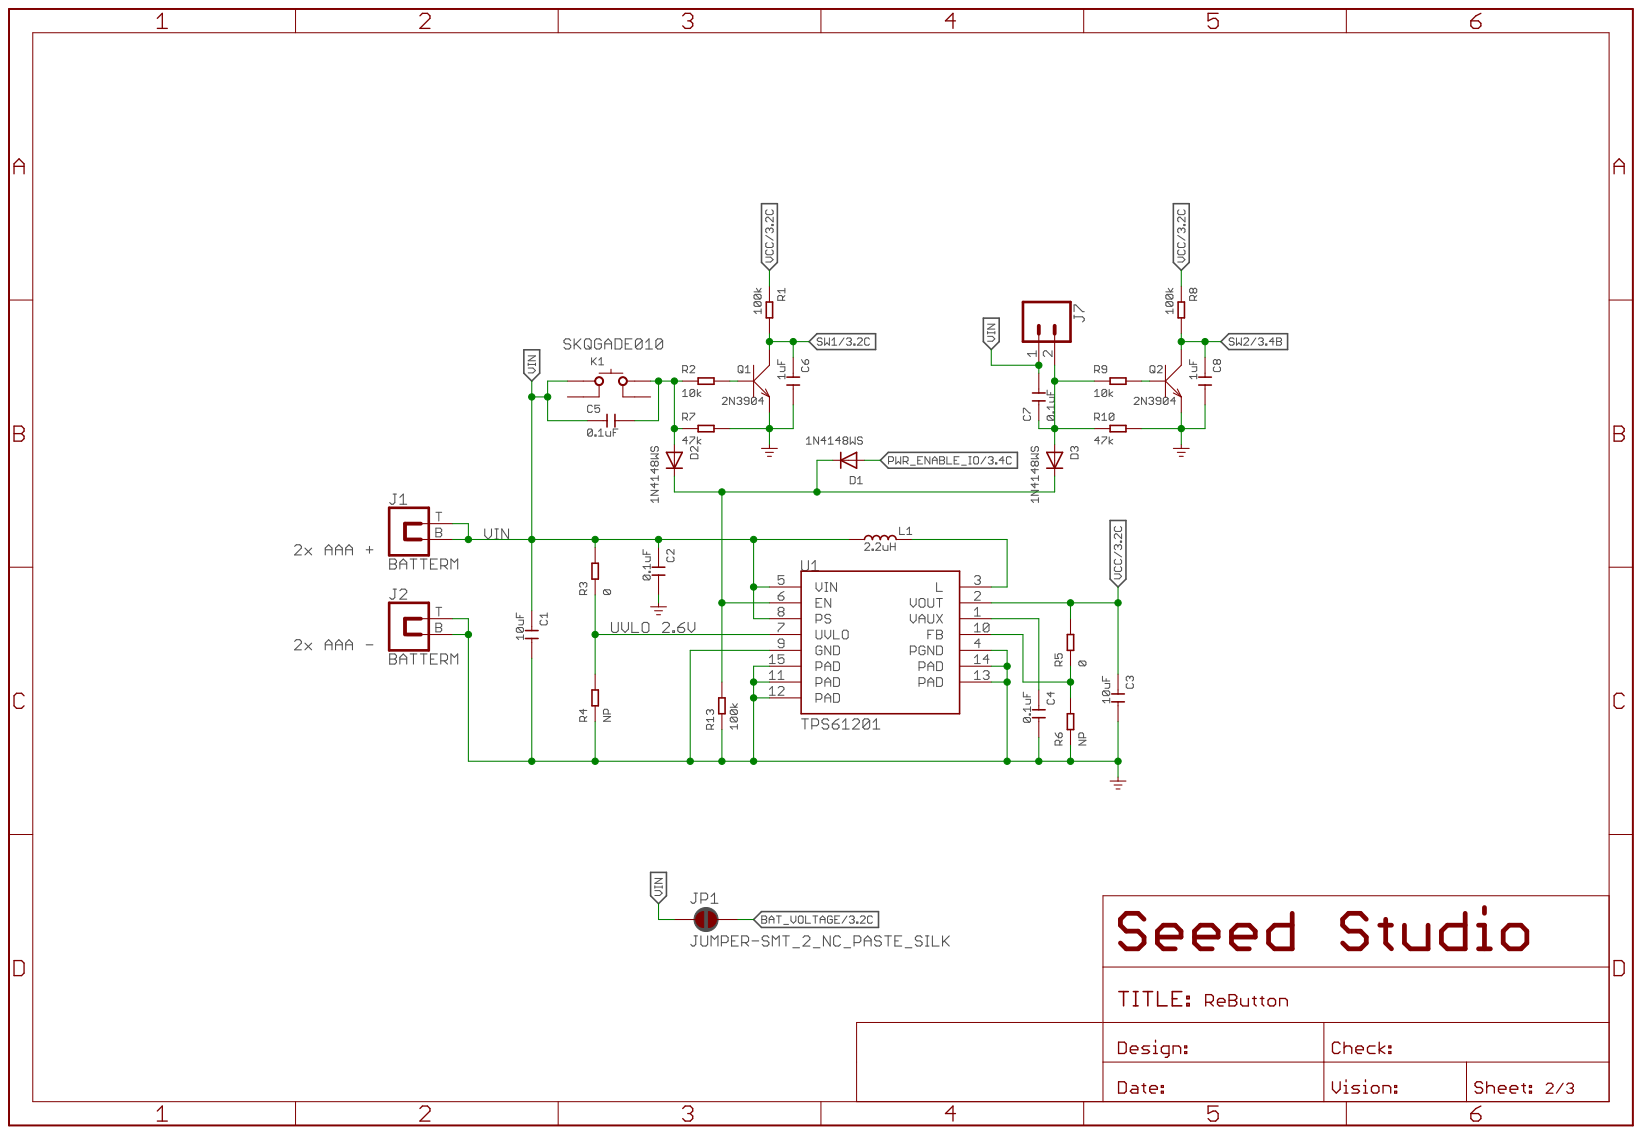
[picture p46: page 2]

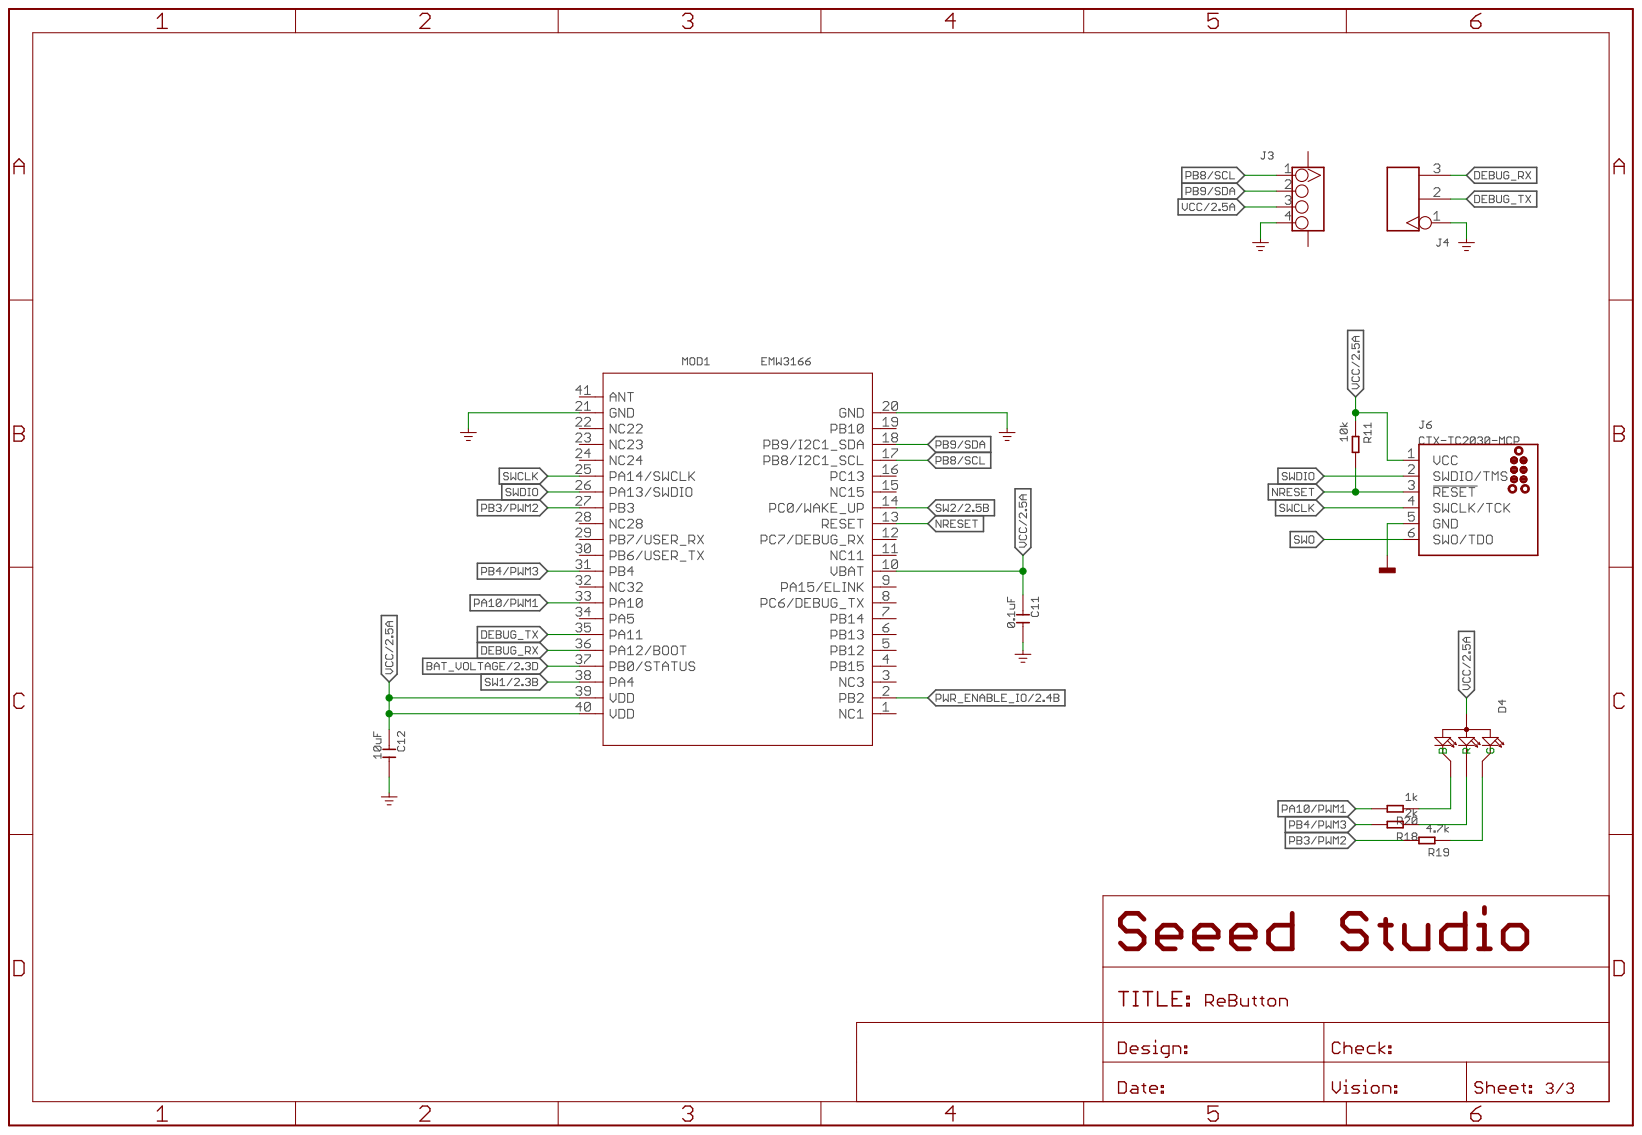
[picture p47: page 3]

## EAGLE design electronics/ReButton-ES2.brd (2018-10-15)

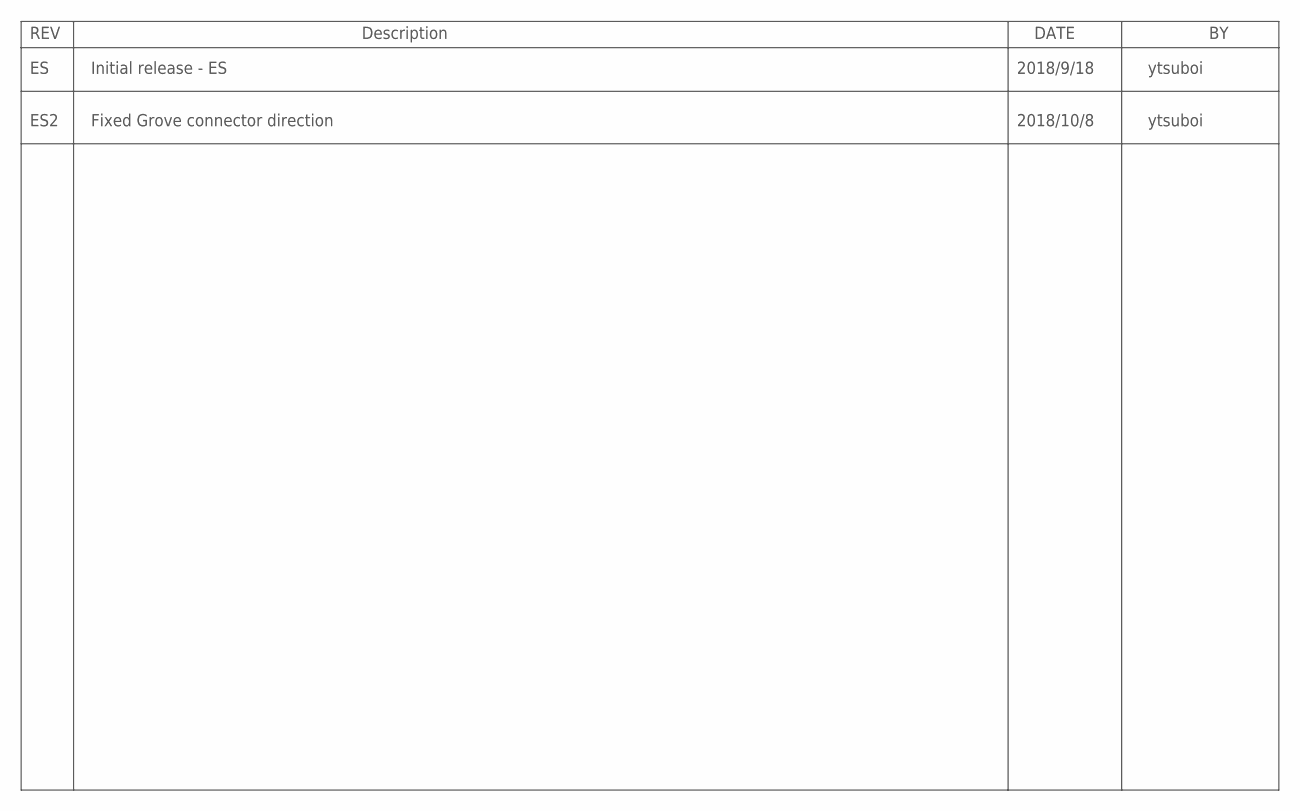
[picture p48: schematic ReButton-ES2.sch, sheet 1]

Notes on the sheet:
Initial release - ES
2018/9/18
ytsuboi
Fixed Grove connector direction
ES2
2018/10/8

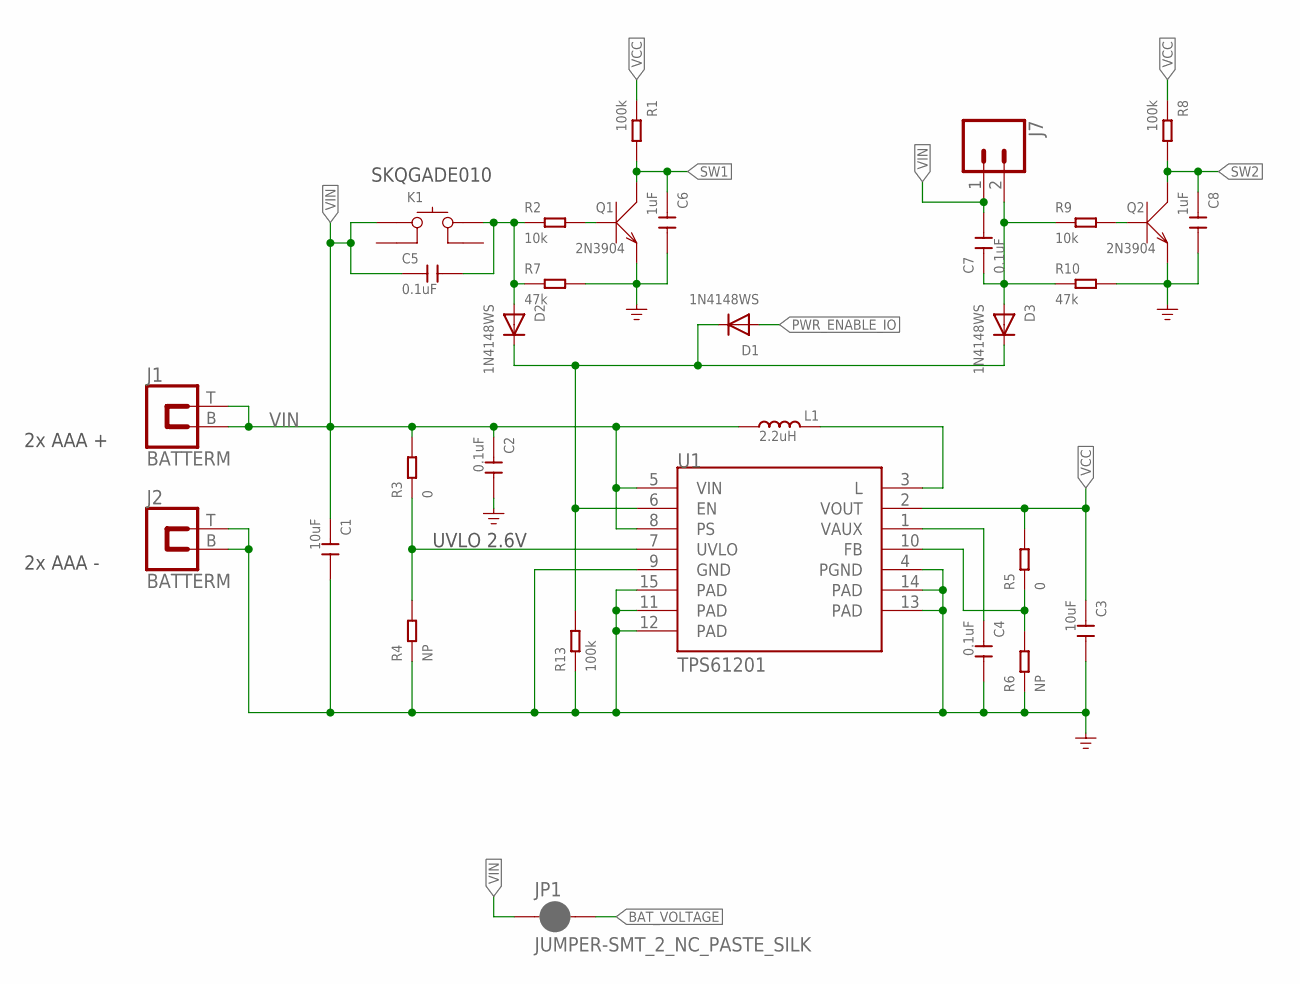
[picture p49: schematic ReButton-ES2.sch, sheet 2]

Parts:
C1, C3: 10uF; C0805
C2, C4, C5, C7: 0.1uF; C0402
C6, C8: 1uF; C0402
D1, D2, D3: 1N4148WS; SOD-323
J1, J2: BATTERM
J7: CONN_02LOCK; 1X02_LOCK
JP1: JUMPER-SMT_2_NC_PASTE_SILK; SMT-JUMPER_2_NC_PASTE_SILK
K1: BUTTON-4P-6.2X6.2; SW4-SMD-6.2X6.2MM
L1: 2.2uH; L3030-TAIYO-YUDEN-NR3012
Q1, Q2: 2N3904; SOT-23
R1, R8, R13: 100k; R0402
R2, R9: 10k; R0402
R3, R5: 0; R0402
R4, R6: NP; R0402
R7, R10: 47k; R0402
U1: TPS61201; QFN-10_PAD

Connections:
BAT_VOLTAGE: JP1.2; also elsewhere on the board
FB: R5.1, R6.2, U1.10 (FB)
GND: C1.2, C2.2, C3.2, C4.2, C6.2, C8.2, J2.B, J2.T, Q1.2 (E), Q2.2 (E), R4.1, R6.1, R7.2, R10.2, R13.1, U1.4 (PGND), U1.9 (GND), U1.11 (PAD), U1.12 (PAD), U1.13 (PAD), U1.14 (PAD), U1.15 (PAD); also elsewhere on the board
unnamed: C4.1, U1.1 (VAUX)
unnamed: L1.2, U1.3 (L)
unnamed: D1.C, D2.C, D3.C, R13.2, U1.6 (EN)
unnamed: Q1.1 (B), R2.2
unnamed: C5.2, D2.A, K1.2 (B0), R2.1, R7.1
unnamed: C7.1, D3.A, J7.2, R9.1, R10.1
unnamed: Q2.1 (B), R9.2
PWR_ENABLE_IO: D1.A; also elsewhere on the board
SW1: C6.1, Q1.3 (C), R1.2; also elsewhere on the board
SW2: C8.1, Q2.3 (C), R8.2; also elsewhere on the board
UVLO: R3.1, R4.2, U1.7 (UVLO)
VCC: C3.1, R1.1, R5.2, R8.1, U1.2 (VOUT); also elsewhere on the board
VIN: C1.1, C2.1, C5.1, C7.2, J1.B, J1.T, J7.1, JP1.1, K1.1 (A0), L1.1, R3.2, U1.5 (VIN), U1.8 (PS)

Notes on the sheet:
UVLO 2.6V
2x AAA +
2x AAA -
SKQGADE010

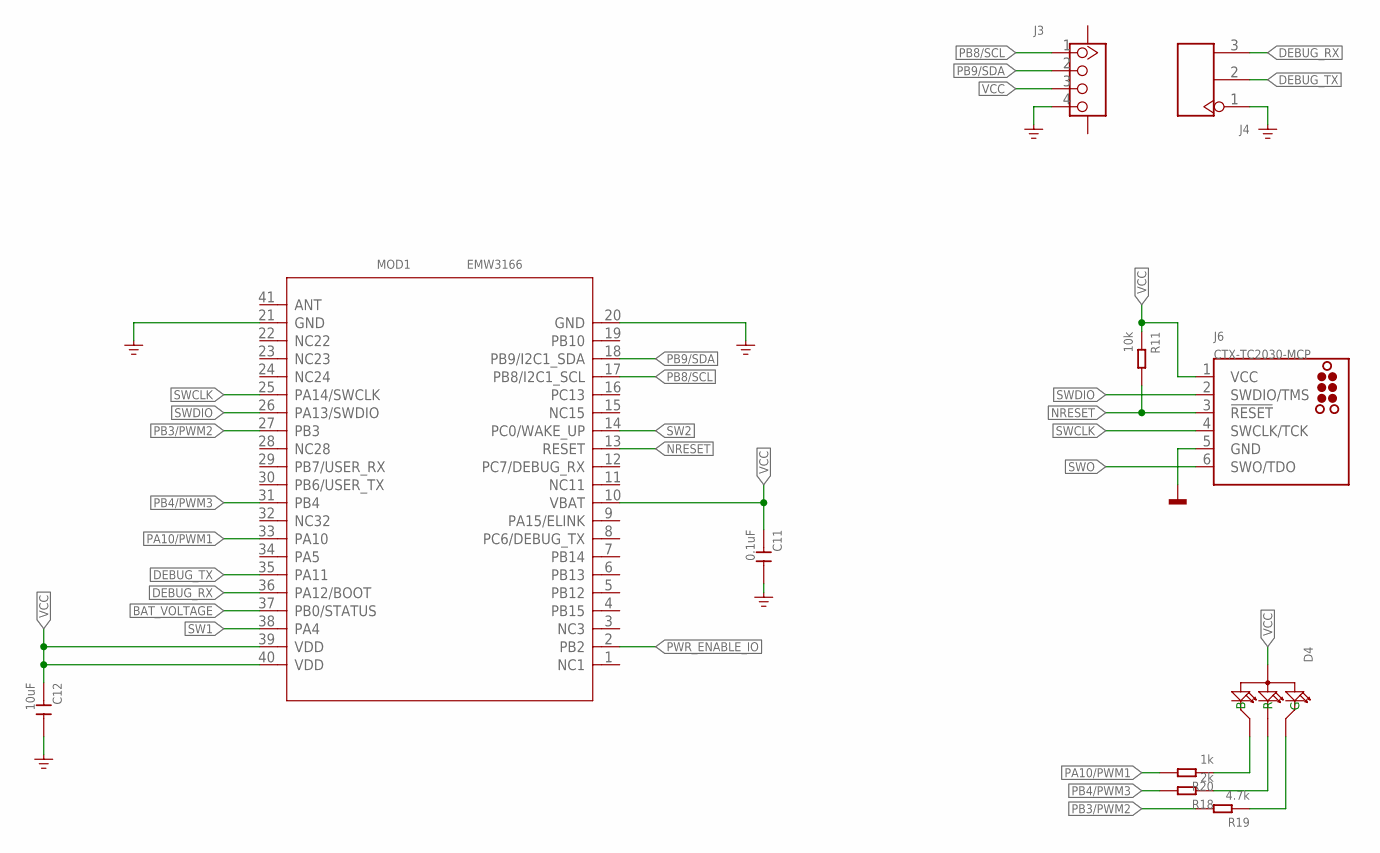
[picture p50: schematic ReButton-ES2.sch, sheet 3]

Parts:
C11: 0.1uF; C0402
C12: 10uF; C0805
D4: LED-ARGB-4P-19-237; LED4-1.6X1.6X0.35MM
J3: GROVE-CONNECTOR-SMD'DD'; HW4-SMD-2.0
J4: HEADER-3P; H3-2.3-65/35MIL
J6: CTX-TC2030-MCP; TC2030-MCP
MOD1: EMW3166; MODULE-WIFI-EMW3166
R11: 10k; R0402
R18: 2k; R0402
R19: 4.7k; R0402
R20: 1k; R0402

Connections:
BAT_VOLTAGE: MOD1.37 (PB0/STATUS); also elsewhere on the board
DEBUG_RX: J4.3, MOD1.36 (PA12/BOOT)
DEBUG_TX: J4.2, MOD1.35 (PA11)
GND: C11.2, C12.2, J3.4, J4.1, J6.5 (GND), MOD1.20 (GND), MOD1.21 (GND); also elsewhere on the board
unnamed: D4.4 (R), R18.1
unnamed: D4.2 (G), R19.1
unnamed: D4.1 (B), R20.1
NRESET: J6.3 (!RESET!), MOD1.13 (RESET), R11.2
PA10/PWM1: MOD1.33 (PA10), R20.2
PB3/PWM2: MOD1.27 (PB3), R19.2
PB4/PWM3: MOD1.31 (PB4), R18.2
PB8/SCL: J3.1, MOD1.17 (PB8/I2C1_SCL)
PB9/SDA: J3.2, MOD1.18 (PB9/I2C1_SDA)
PWR_ENABLE_IO: MOD1.2 (PB2); also elsewhere on the board
SW1: MOD1.38 (PA4); also elsewhere on the board
SW2: MOD1.14 (PC0/WAKE_UP); also elsewhere on the board
SWCLK: J6.4 (SWCLK/TCK), MOD1.25 (PA14/SWCLK)
SWDIO: J6.2 (SWDIO/TMS), MOD1.26 (PA13/SWDIO)
SWO: J6.6 (SWO/TDO)
VCC: C11.1, C12.1, D4.3 (+), J3.3, J6.1 (VCC), MOD1.10 (VBAT), MOD1.39 (VDD), MOD1.40 (VDD), R11.1; also elsewhere on the board

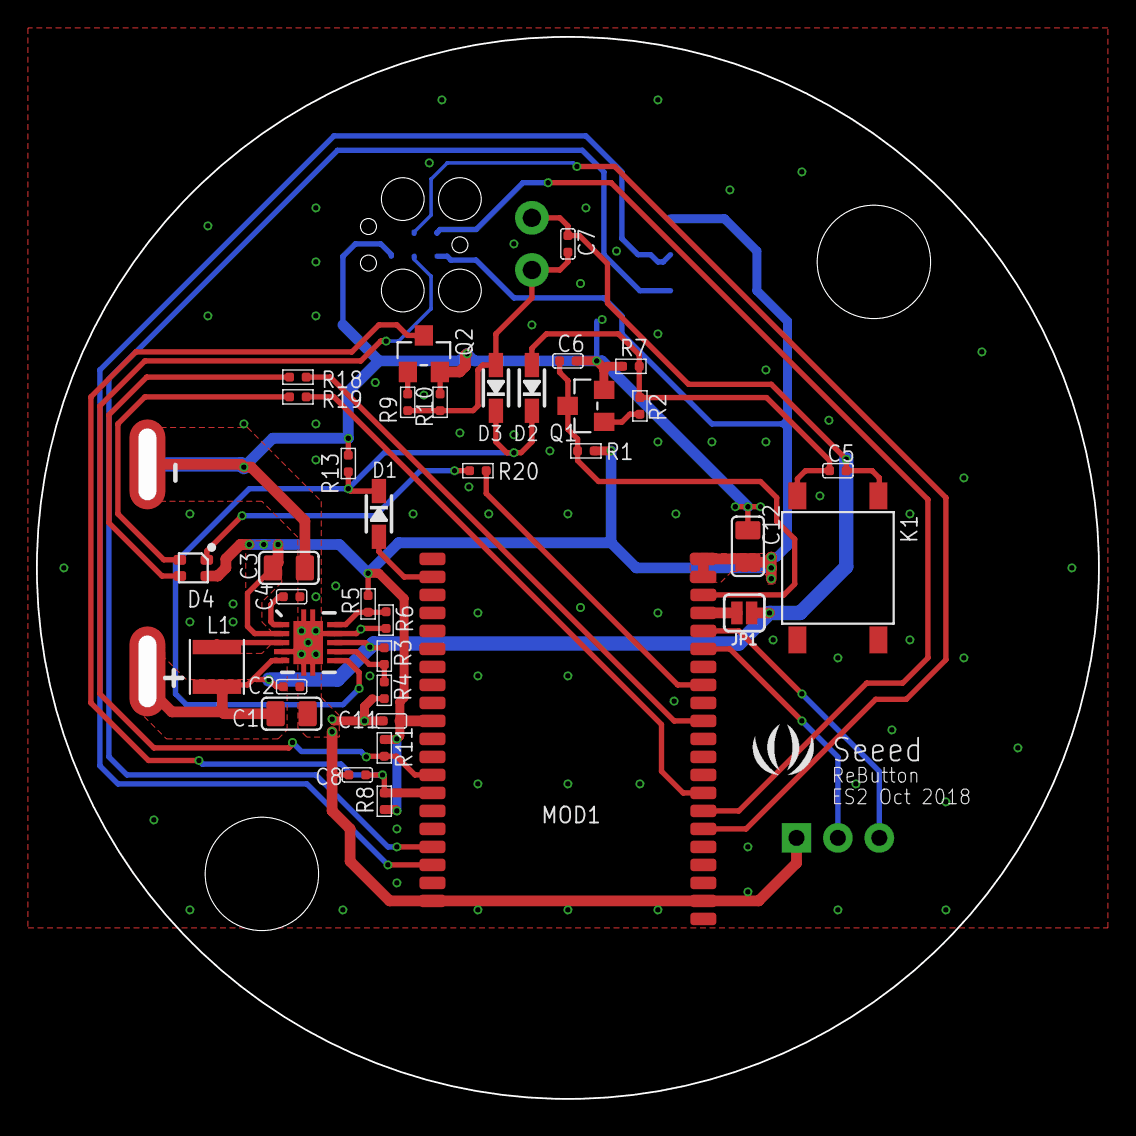
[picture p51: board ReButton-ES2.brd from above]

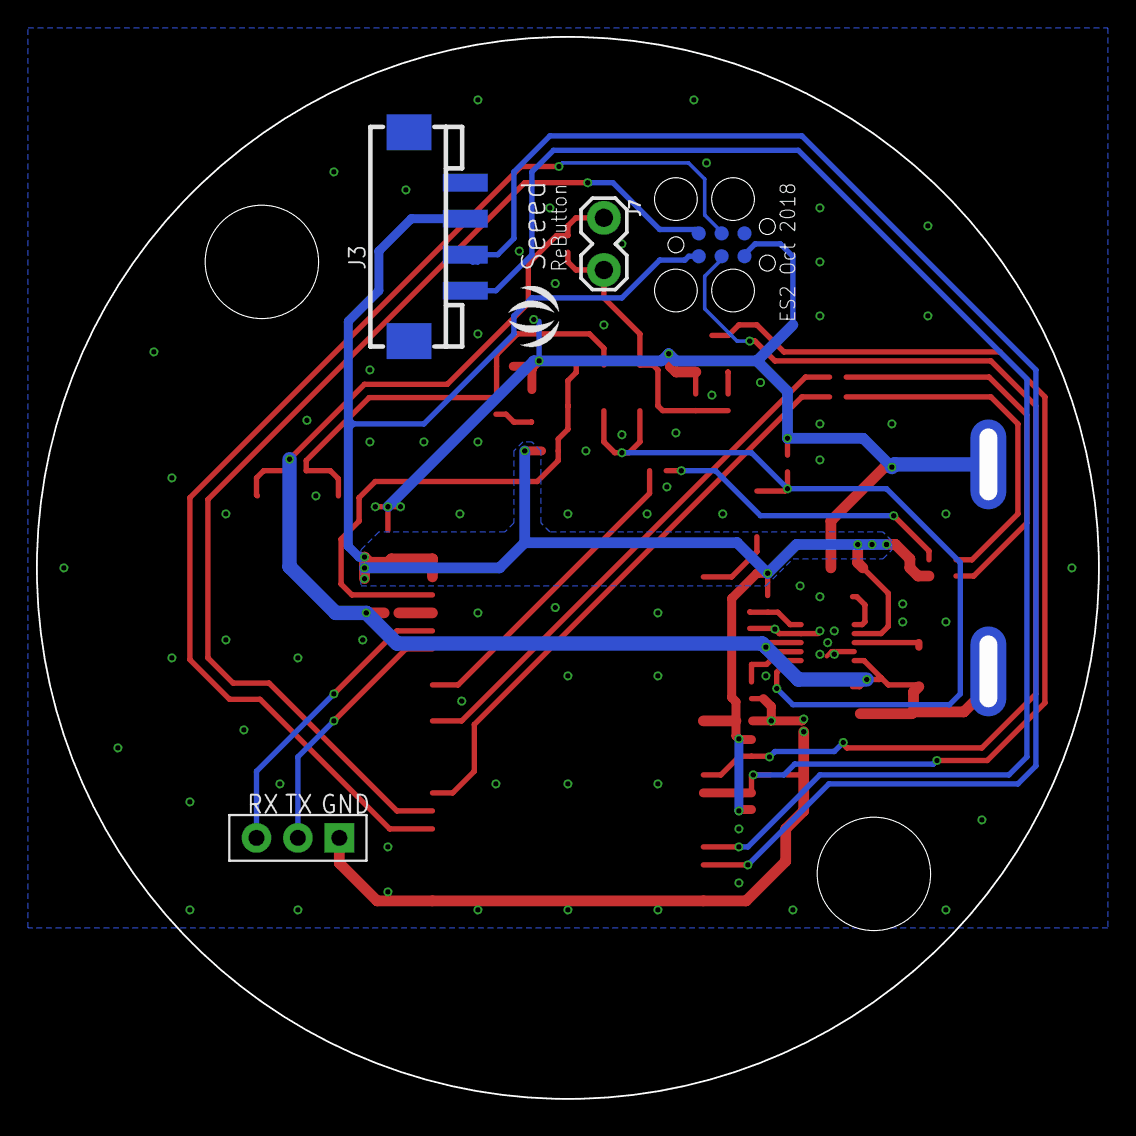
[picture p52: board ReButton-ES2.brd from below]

Board: 2 copper layers, 59.0 x 59.0 mm, 44 parts (5 on the bottom side), 29 nets.

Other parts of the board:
U$9, U$15: SEEED-SILK--TNAME-160*153MIL

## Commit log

2018-10-15 1st commit
    [ReButton-ES2.brd, ReButton-ES2.sch, ReButton.stp]
2019-04-25 Change board manager url
2019-05-31 Japanese document release
    Added link to Japanese version.
    Fixed typo.
    Added note to recommend using fresh battery,
2021-06-07 Updated tables and images for current IoT Central

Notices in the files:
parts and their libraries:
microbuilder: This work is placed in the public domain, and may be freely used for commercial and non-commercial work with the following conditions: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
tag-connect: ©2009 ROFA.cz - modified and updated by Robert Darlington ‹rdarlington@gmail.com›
